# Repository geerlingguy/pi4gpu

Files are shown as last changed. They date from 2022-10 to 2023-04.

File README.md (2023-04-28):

# Pi4GPU - Raspberry Pi CM4 GPU Carrier Board

_a.k.a. 'PiG'_

This project contains the code and designs for a carrier board intended to unite a Raspberry Pi Compute Module 4 to any manufacturer's GPU.

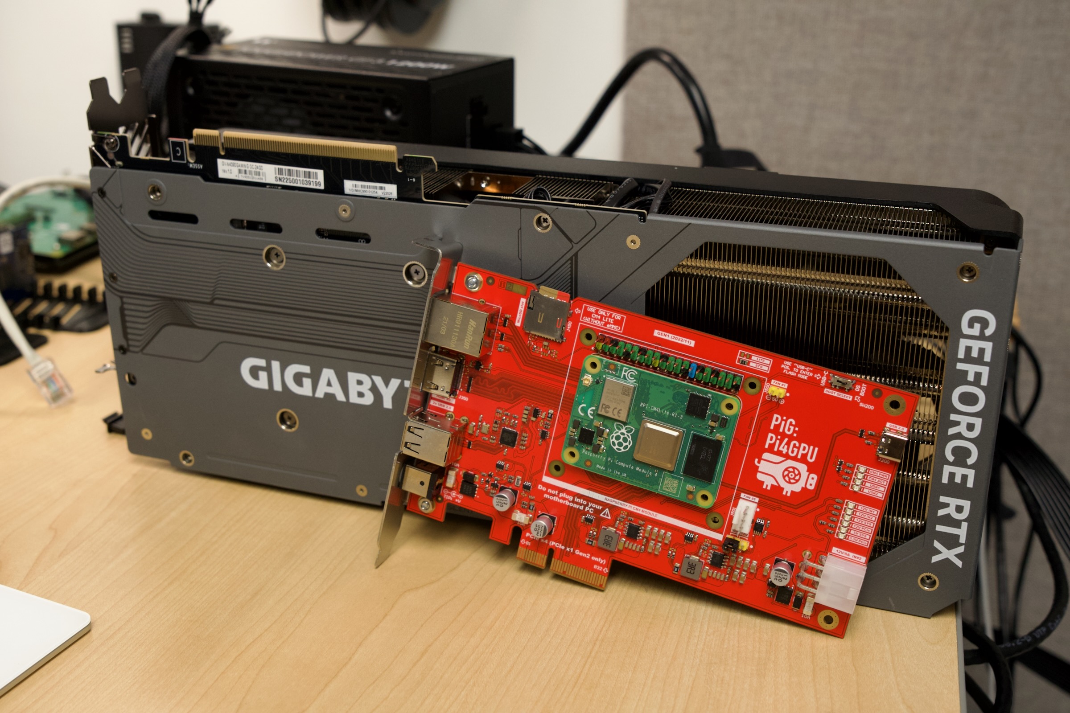
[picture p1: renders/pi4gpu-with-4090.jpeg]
Pi4GPU with Raspberry Pi Compute Module 4 in front of Nvidia GeForce RTX 4090


The board is not exclusively intended for GPU testing, though—this project is helpful for testing any kind of full-size PCI Express card with a Raspberry Pi Compute Module 4 or any CM4-compatible System on Modules (SoM).

## Goals

This project includes all the design files to build the Pi4GPU project:

  - **CM4 carrier board** (with PCIe x4 edge connection)
    - 1x full-size HDMI (rear)
    - 1x RJ45 Ethernet (rear)
    - 2x USB 2.0 (rear)
    - 1x 12v barrel power plug (rear)
    - 1x microSD card slot for Lite CM4 (top)
    - 4-pin PWM fan header with EMC2301 fan controller for optional fan (possibly)
  - **PCIe adapter board**
    - 1x x4 (x1 signaling) PCI Express slot for CM4 carrier board
    - 1x x16 (x1 signaling) PCI Express slot for GPU or other device
  - **3D printed stand**
    - Stable base for the Carrier board, extends to support 3+ slot GPUs
    - Mounting points for PCIe card brackets (in the future)

## Current Status

Early prototype. It works, but there are plenty of improvements to be made! Check out the issues for current work and future improvements.

## License

PCB project published as Open Source Hardware (OSHW) under CERN OHL v1.2 (Open Hardware License).

Pi4GPU has been certified as Open Source Hardware by the Open Source Hardware Association (OSHWA). 

UID is (for v1): PL000014

https://certification.oshwa.org/pl000014.html

UID is (for v2): PL000016

https://certification.oshwa.org/pl000016.html

## People

Pi4GPU was originally designed by:

  - [Jeff Geerling](https://www.jeffgeerling.com) (concept)
  - [@mfolejewski](https://github.com/mfolejewski) (PCB design)

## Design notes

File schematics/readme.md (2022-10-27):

# Description
Here you can find schematics files in PDF format

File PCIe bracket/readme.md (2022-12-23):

PCIe bracket ("Standard Add-in Card I/O Bracket") according to "PCI Express Card Electromechanical Specification Revision 3.0".

Designed by: Adam Nowak (with small modifications) based on the 3D model from GrabCAD: https://grabcad.com/library/pcie-brackets-1

Known issues:
- missing M3 threads (2 pcs) -> attached picture ("PCIe_bracket_M3_hole.png")
- missing bending -> attached picture ("PCIe_missing_bending.png")
- 3D model should be verified with the existing hardware

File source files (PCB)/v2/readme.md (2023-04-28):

## PCB project

Here the design files (schematic, PCB, BOM) can be viewed by using interactive service (Altium 365 platform):
https://365.altium.com/files/2EB381B2-202C-4C54-8FDE-9D991AE2ABAC

## License

Project published as Open Source Hardware (OSHW) under CERN OHL v1.2 (Open Hardware License).



Project (v2) has been certified as Open Source Hardware by the Open Source Hardware Association (OSHWA).

UID is (v2): PL000016

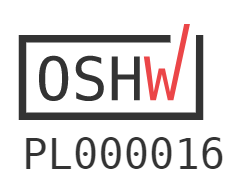
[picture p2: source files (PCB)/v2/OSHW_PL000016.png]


https://certification.oshwa.org/pl000016.html

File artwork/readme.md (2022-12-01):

PiG artwork has been designed by Senior Graphic Designer Krystyna Oniszczuk-Dylik:
https://www.linkedin.com/in/krystyna-oniszczuk-dylik-2559ab151/

Here you can download PNG and PDF file which contain this graphic design:
https://github.com/geerlingguy/pi4gpu/blob/master/artwork/PiG_2022-11-28.png
https://github.com/geerlingguy/pi4gpu/blob/master/artwork/PiG_2022-11-28.pdf

Here is preview of the artwork placed on the PCB:
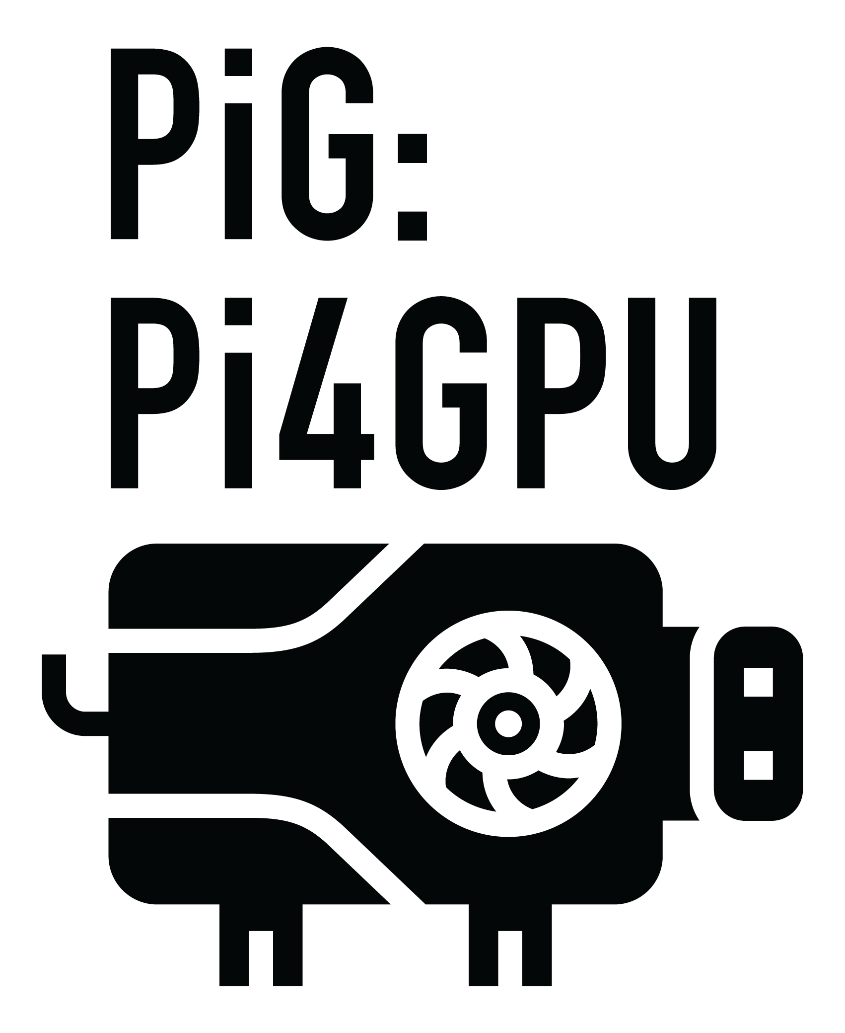
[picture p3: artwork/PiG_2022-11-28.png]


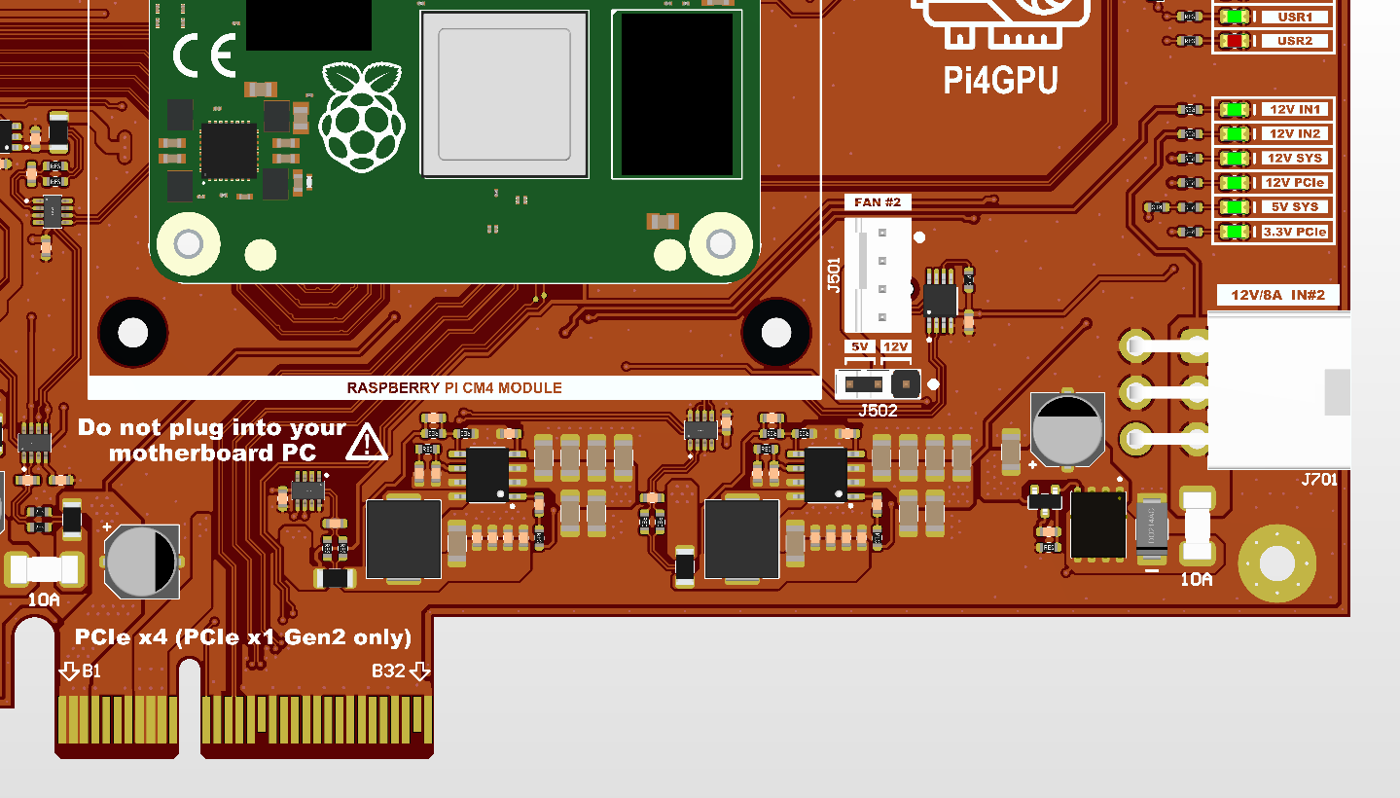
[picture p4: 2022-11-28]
renders/Pi4GPU_2022-11-29_4.png

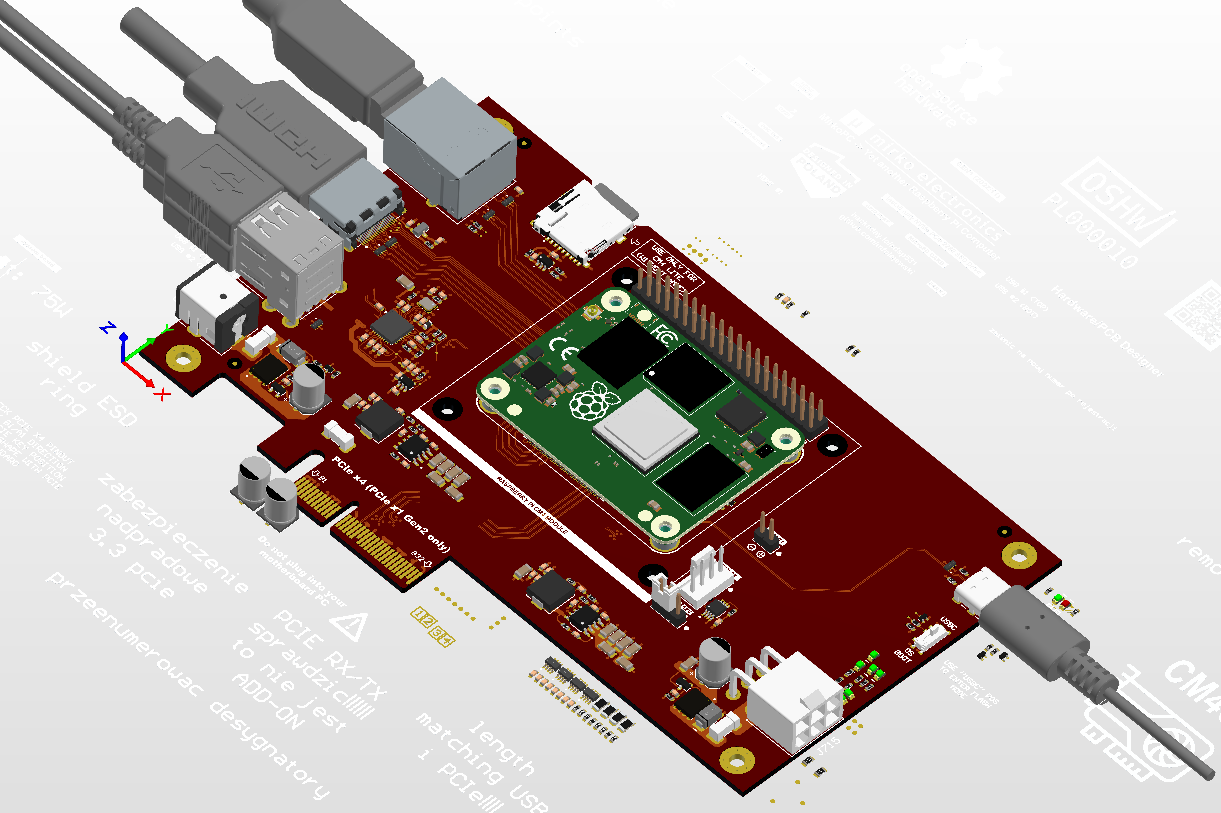
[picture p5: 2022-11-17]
renders/CM4GPU_PCB_20221117_04.png

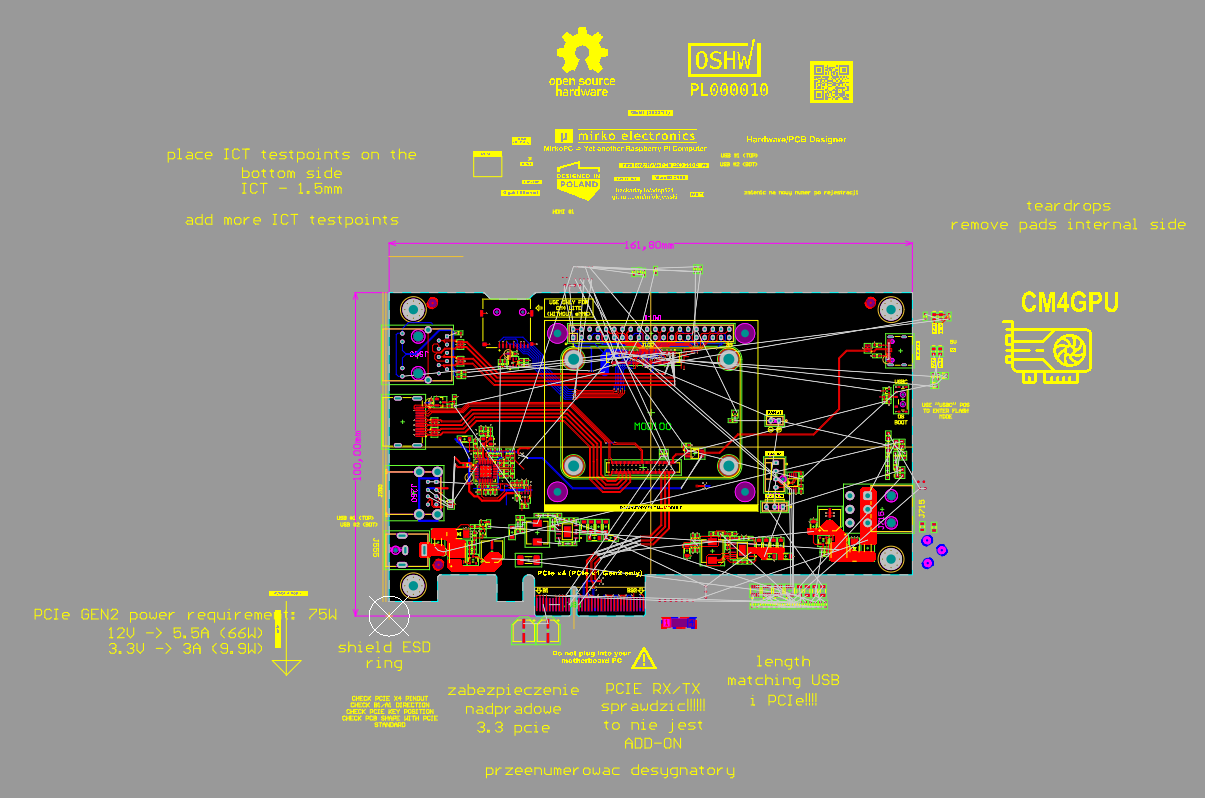
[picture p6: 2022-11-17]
renders/CM4GPU_PCB_20221117_01.png

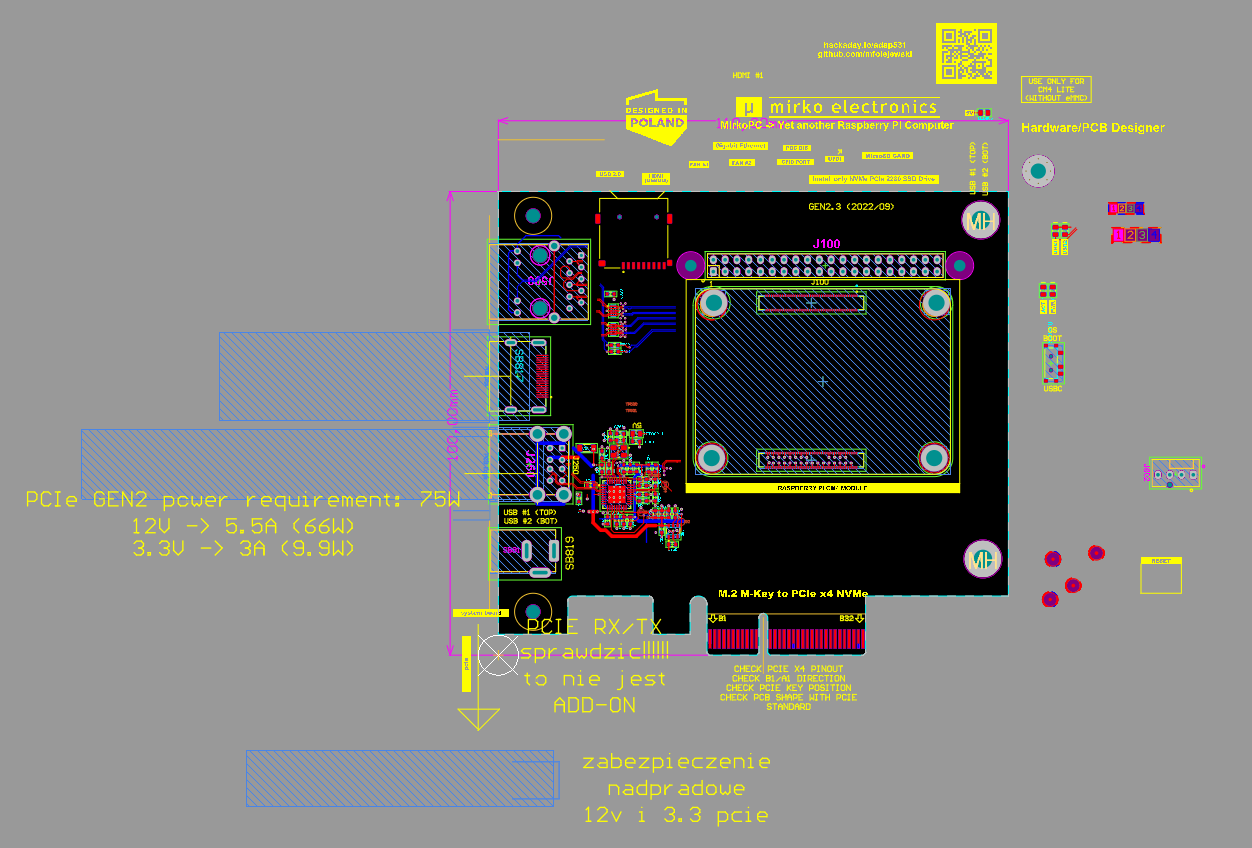
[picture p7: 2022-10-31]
renders/CM4GPU_PCB_20221031_04.png

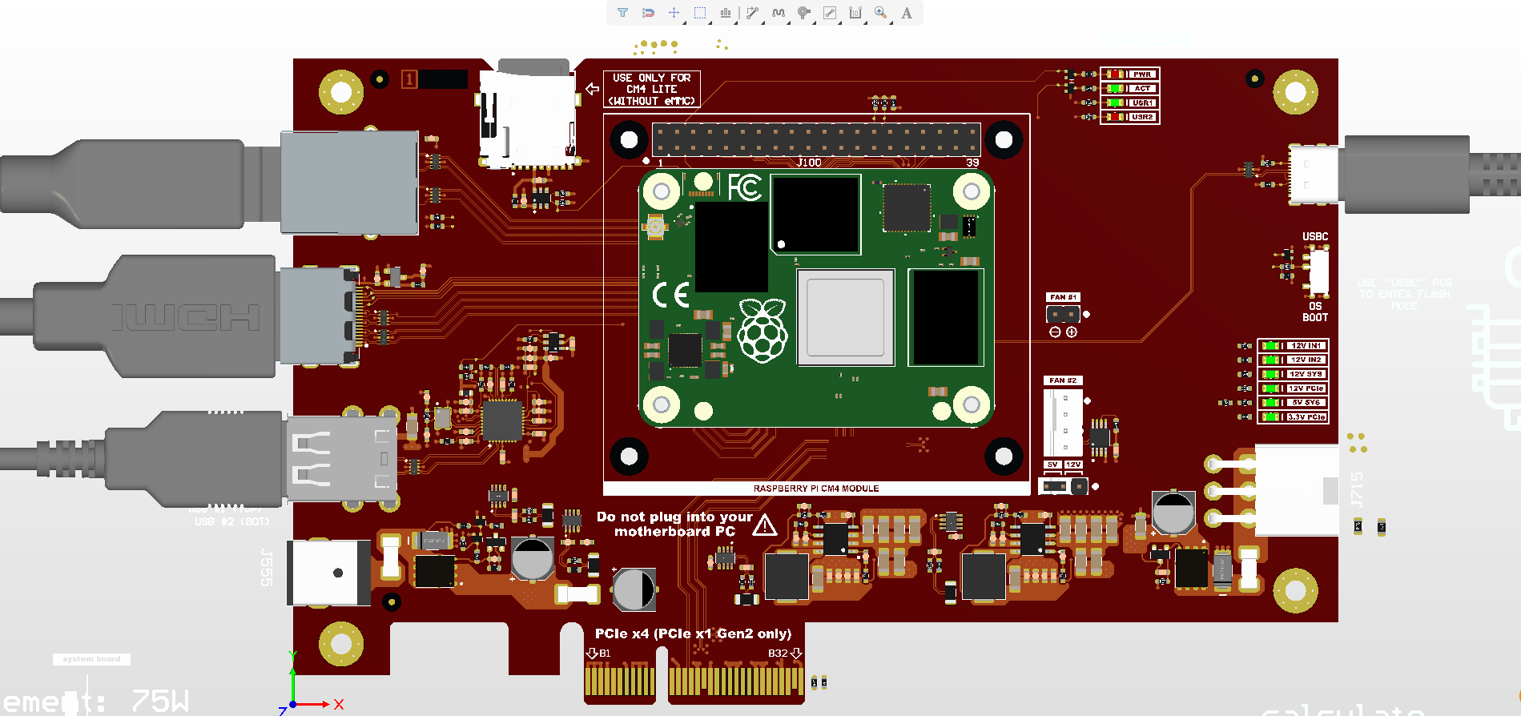
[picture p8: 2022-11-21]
renders/Pi4GPU_2022-11-21_1.png

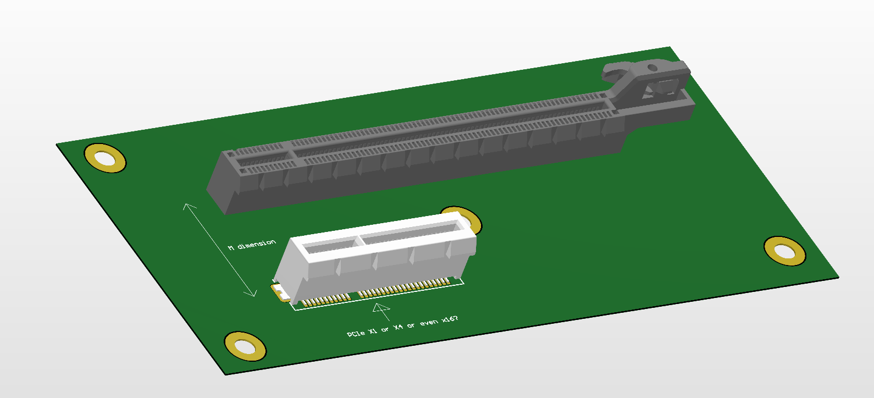
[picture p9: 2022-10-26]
renders/PCIE_adapter1.png

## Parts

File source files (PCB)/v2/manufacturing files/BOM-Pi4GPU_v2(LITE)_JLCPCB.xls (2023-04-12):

Comment | Designator | Footprint | LCSC PN
0R | R450 | 0603 (1608) | C21189
0R | R900 | 0805 (2012) | C17477
0.004R | R807 | 1206 (3216) | C5120913
0.012R | R800, R806, R812 | 1206 (3216) | C723448
0.016R | R801 | 1206 (3216) | C2904218
1k | R200, R203 | 0603 (1608) | C21190
1M | R256 | 0603 (1608) | C22935
1.2nF | C765, C781 | 0603 (1608) | C1853470
2k | R101, R102, R104, R106, R502 | 0603 (1608) | C22975
2k26 | R760 | 0603 (1608) | C22904
3.3uH | L750, L751 | SMD | C524605
4u7 | C256, C261 | 0603 (1608) | C19666
5k1 | R201, R202 | 0603 (1608) | C23186
8A, 2.0mm | J700 | THT | 490-PJ-063AH
10A/125VDC | FUS700, FUS701, FUS702 |  | C2838934
10k | R103, R252, R253, R254, R255 | 0603 (1608) | C98220
10R | R750, R755 | 0603 (1608) | C22859
10uF | C250, C252, C253, C254, C255, C451 | 0603 (1608) | C19702
10uF/10V | C755, C756, C757, C758, C771, C772, C773, C774 | 0603 (1608) | C19702
10uF/35V | C703, C751, C752, C753, C761, C762, C763, C767, C768, C769, C777, C778, C779 | 1206 (3216) | C92797
12k | R250 | 0603 (1608) | C22790
12k | R251, R753, R757 | 0603 (1608) | C22790
12V | D700, D702 |  | C896784
15k | R105, R501, R703, R709, R751, R756, R758 | 0603 (1608) | C22809
15k | R754 | 0603 (1608) | C22809
18pF | C266, C267 | 0603 (1608) | C1647
20k | R759 | 0603 (1608) | C4184
24.000MHz | X250 |  | C5261153
40pin (2x20pin) | J100 |  | C124383
47k | R752 | 0603 (1608) | C25819
100k | R700, R701 | 0603 (1608) | C25803
100nF | C200, C257, C258, C259, C260, C262, C263, C350, C351, C400, C750, C760, C766, C776, C803 | 0603 (1608) | C14663
100nF/50V | C700, C702 | 0603 (1608) | C14663
100R | R100, R107, R108, R109, R258 | 0603 (1608) | C22775
100uF/6V3 | C251 | 1206 (3216) | C15008
100uF/10V | C759, C775 | 1206 (3216) | C15008
120 Ohm | F250 | 0603 (1608) | C62708
220uF/25V | C701, C704, C705 | SMD SIZE D8 | C2918361
470R | R400, R401 | 0603 (1608) | C23179
AP2331 | U352 | SC59 | C460346
AP2553W6-7 | U250 | SOT26 | C212302
AP64501SP-13 | U750, U751 |  | C2071517
CON HDR 1x2 | J500 | THT | C492401
DTA143ZE | Q100, Q101 |  | C600679
DTC143ZE | Q200, Q500 |  | C248787
FSUSB42 | U200 | MSOP-10 | C255478
Green | LED100, LED500, LED700, LED701, LED750, LED751 | 0805 (2012) | C84260
HY911130A | J400 |  | C55679
Mezzanine, 100pin, 3.0mm | J101, J102 | SMD | C424649
MicroSD Card (Slot) | J450 | SMD | C113206
Molex 2x3P 4.2mm | J701 | THT | C54904
PCB BARE BOARD | PCB1
PMOS | Q700, Q703 | PowerPAK-SO-8 | C554002
RCLAMP0524PA | U201, U252, U350, U351, U400, U401 | TBD | C40960
Red | LED101, LED501 | 0805 (2012) | C84256
RPi CM4 Module | MOD100
Slide switch | SW200 | SMD | C397350
SMAJ12A | D701, D703 |  | C713694
SPST | SW100, SW101 | SMD | C110293
Standdard HDMI (Type A) | J350 | SMD | C138388
U262-161N-4BVC11 | J200 | SMD | C319148
USB2512B | U251 |  | C626658
USB Type A (Dual) | J250 | THT | C456021

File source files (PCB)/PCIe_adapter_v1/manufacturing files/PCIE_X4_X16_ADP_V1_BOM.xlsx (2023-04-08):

Designator | Quantity | Component Type | Value | Package (Case) | Manufacturer | MPN | Description
J1 | 1 |  | PCIE x16, 164P, SMD |  | UMAX | 91621-120113N | Connector; PCIE x16 (164 pin)
J2 | 1 |  | PCIE x4, 64P, SMD |  | UMAX | UMAX 3113-111T | Connector; PCIE x4 (64 pin)
R1, R2, R3, R4, R5, R6, R7, R8, R9, R10 | 10 | Resistor | DNP | 0603 (1608) | TBD | TBD | Resistor; Thick Film; DNP; TBD; TBD; TBD; TBD; DO NOT PLACE; SMD; 0603 (1608);

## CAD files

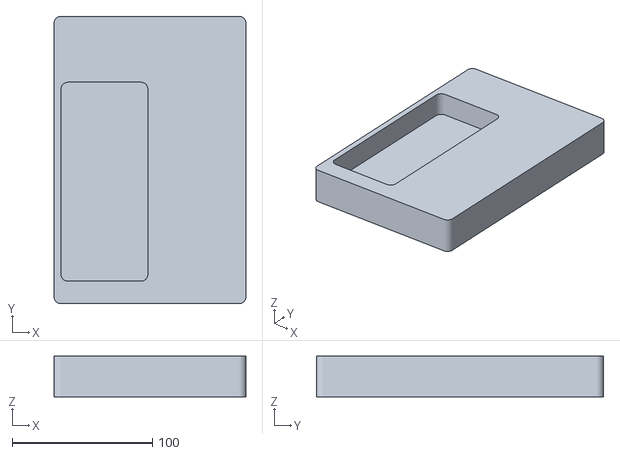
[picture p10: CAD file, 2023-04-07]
3d-models/gpu-stand.stl
137.0 x 205.0 x 29.0

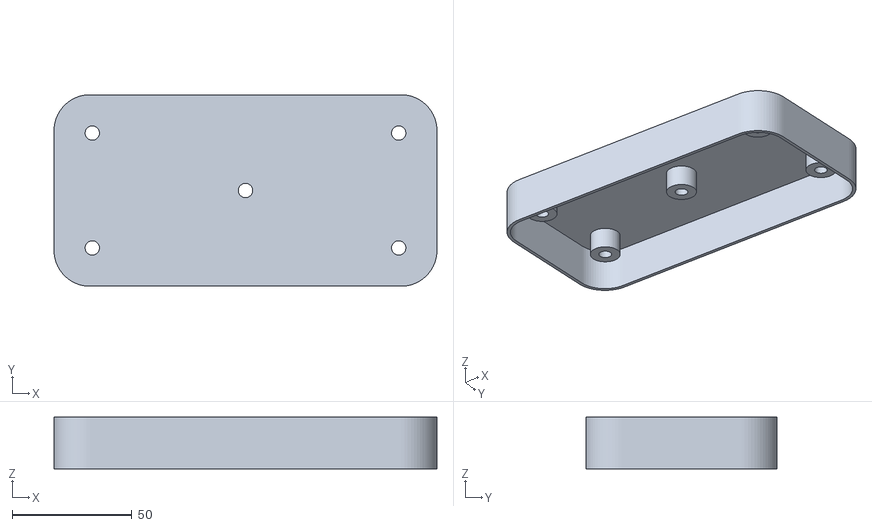
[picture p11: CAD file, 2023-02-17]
STEP models/PCIE_X4_X16_ADP_stand_v1.stl
160.0 x 80.0 x 21.6

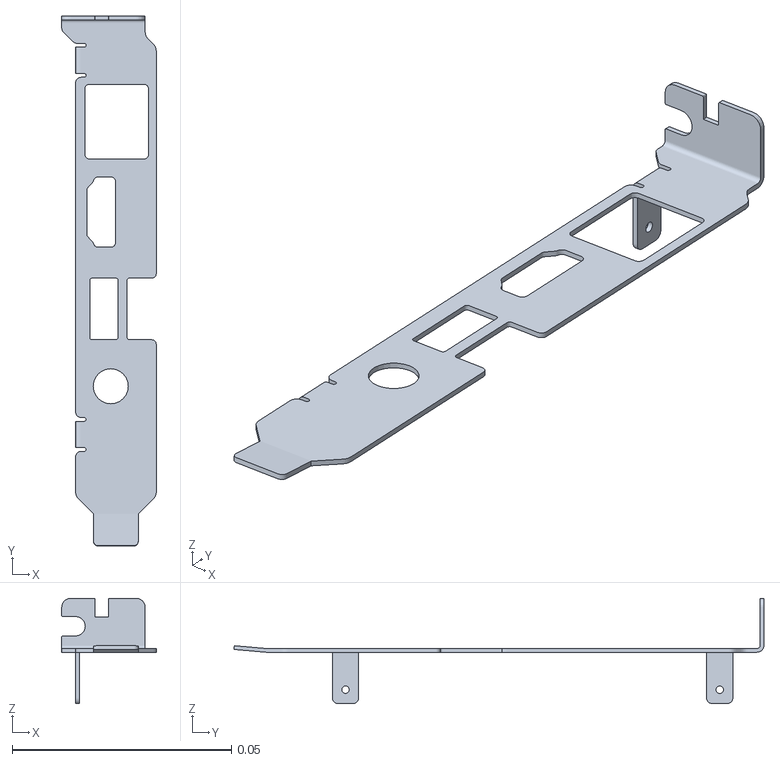
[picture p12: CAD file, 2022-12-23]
PCIe bracket/PCIE card IO panel.stl
0.0216 x 0.121 x 0.024

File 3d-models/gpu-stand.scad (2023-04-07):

$fn = $preview ? 32 : 64;

// Main body.
translate([5, 5, 0])
    difference() {
        minkowski() {
            cube(size = [127,195,28], center = false);
            cylinder(r=5, h=1, center = false);
        }
        translate([5, 16, 10]) {
            minkowski() {
                cube(size = [52,132,20], center = false);
                cylinder(r=5, h=28, center = false);
            }
        }
    }

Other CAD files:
PCIe bracket/PCIE card IO panel 4 mif.DWG

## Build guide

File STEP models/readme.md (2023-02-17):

Here you can download 3D STEP models of PCB boards and other parts:

PCIE_X4_X16_ADP_stand_v1.stl -> simple stand for test setup (v1)
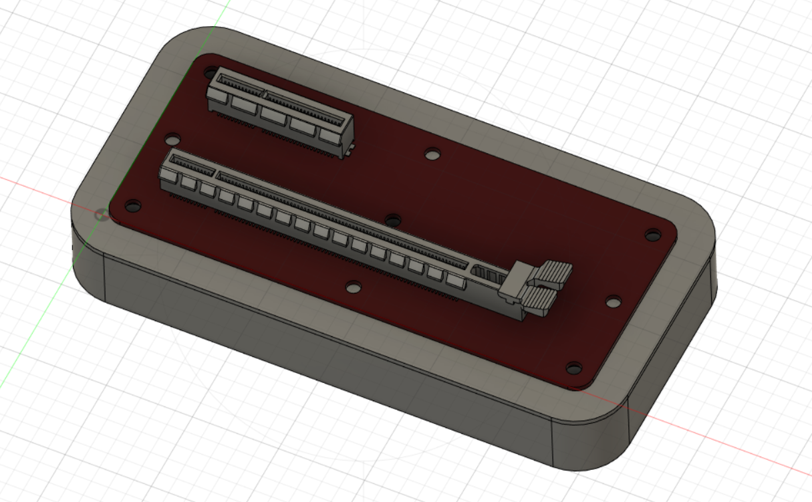
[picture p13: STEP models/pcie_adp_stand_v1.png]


PCIE_X4_X16_ADP_V1_STEP_3D_2022-12-20.7z -> PCIe X4-X16 adapter (PCB + all the components)
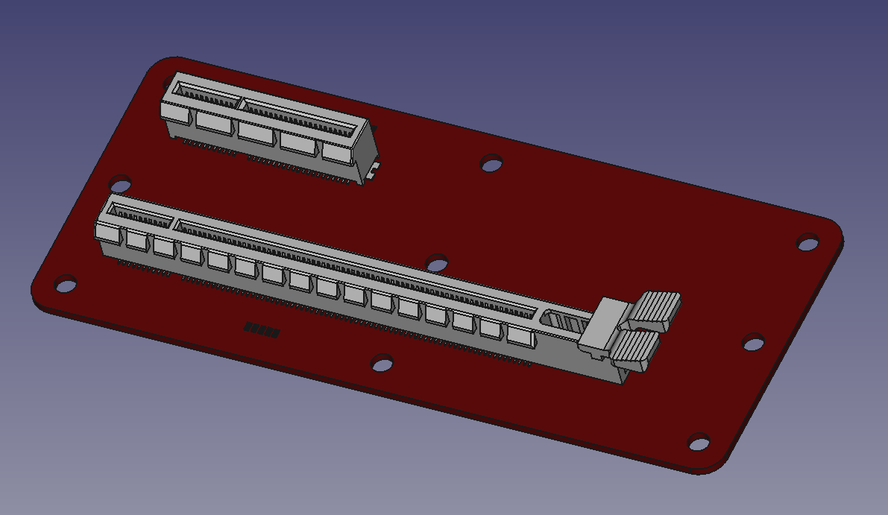
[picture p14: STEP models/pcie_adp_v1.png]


Pi4GPU_v1_3D_model_20221129_full.7z -> (PCB + all the components)
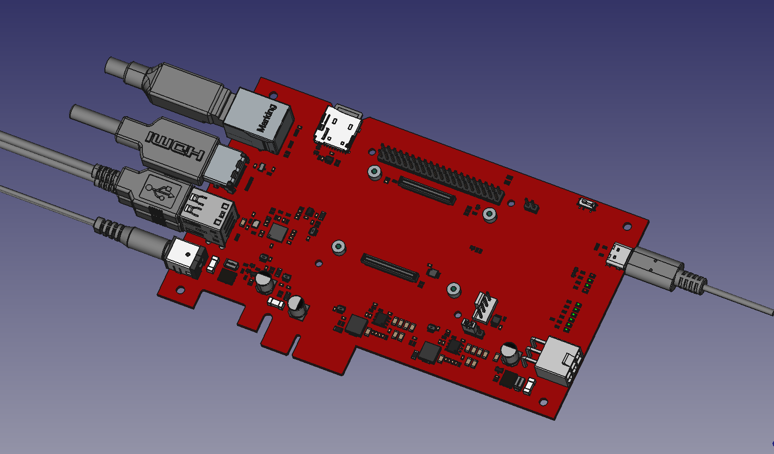
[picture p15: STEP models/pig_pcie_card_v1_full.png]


Pi4GPU_v1_3D_model_20221129_conn_only.7z -> (PCB + front connectors only)
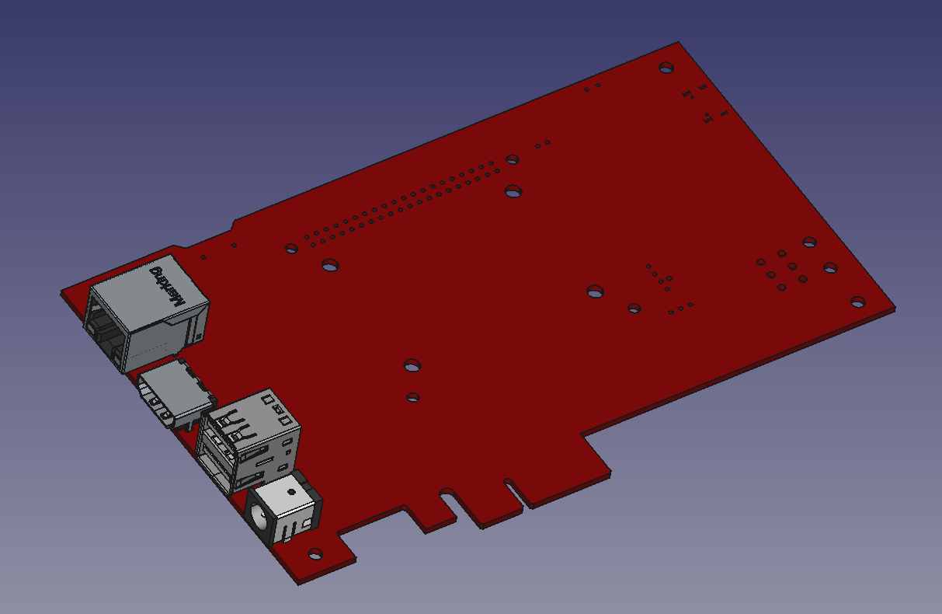
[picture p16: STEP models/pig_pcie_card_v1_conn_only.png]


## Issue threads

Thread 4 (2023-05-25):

[feature idea] power options

8bitbunny, 2023-05-25:
i there are multiple options for powering this unit (pcie 6pin, dc barrel), which is nice

one feature i do suggest for a faster and more convenient install: putting the pcie 6 pin connector on the pcie bridge to both gpu and pi4gpu card using different connectors, like 8 pin pcie, or eps12v, or atx12vo?
just so theres cables to deal with when swapping pi4gpu card and you have more modularity power wise.

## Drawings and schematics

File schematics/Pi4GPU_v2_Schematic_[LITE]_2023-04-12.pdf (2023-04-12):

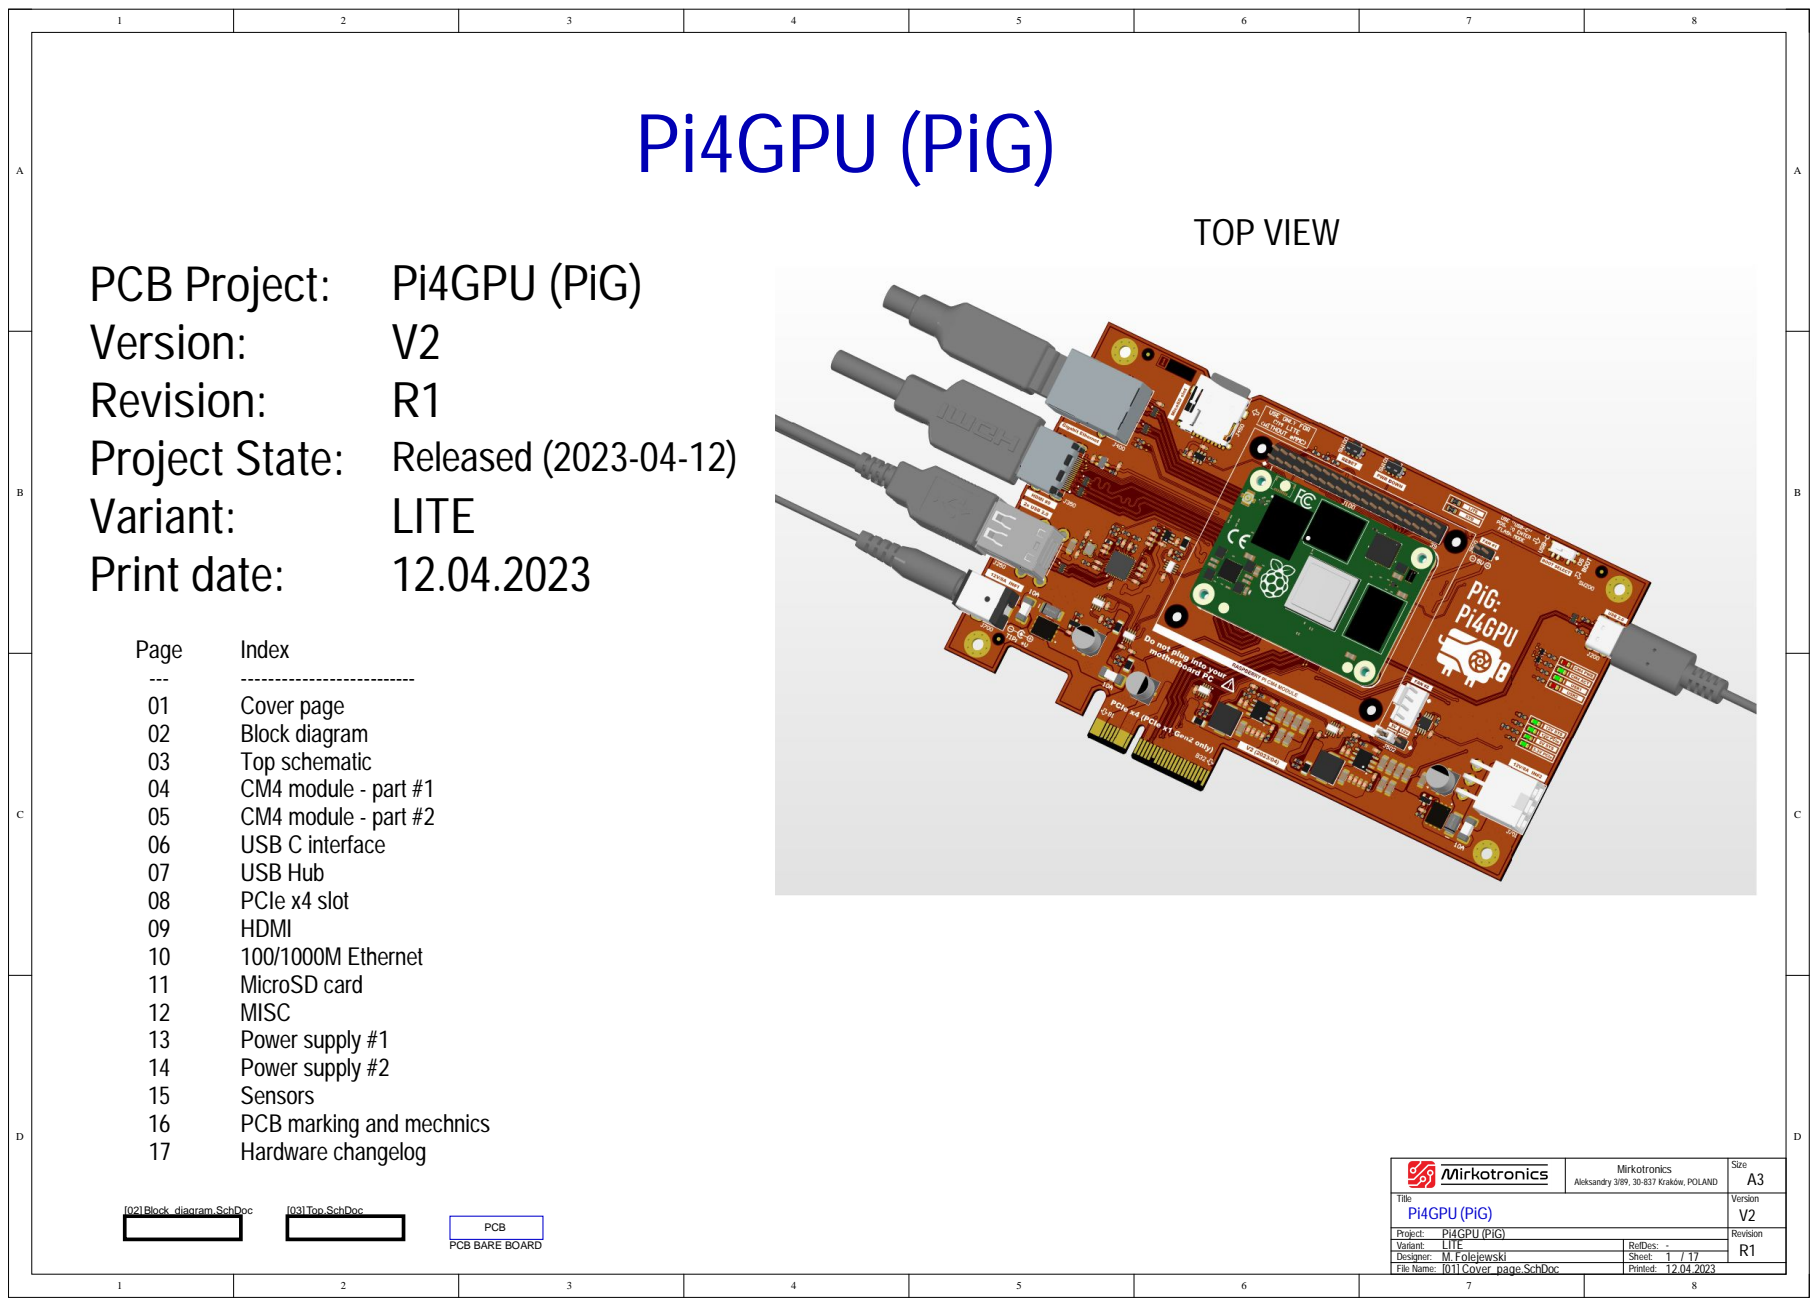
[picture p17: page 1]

Mirkotronics Aleksandry 3/89, 30-837 Kraków, POLAND | Size A3

Title Pi4GPU (PiG) | | Version V2

Revision R1
Variant: LITE
Designer: M. Folejewski
File Name: [01] Cover_page.SchDoc | Printed:

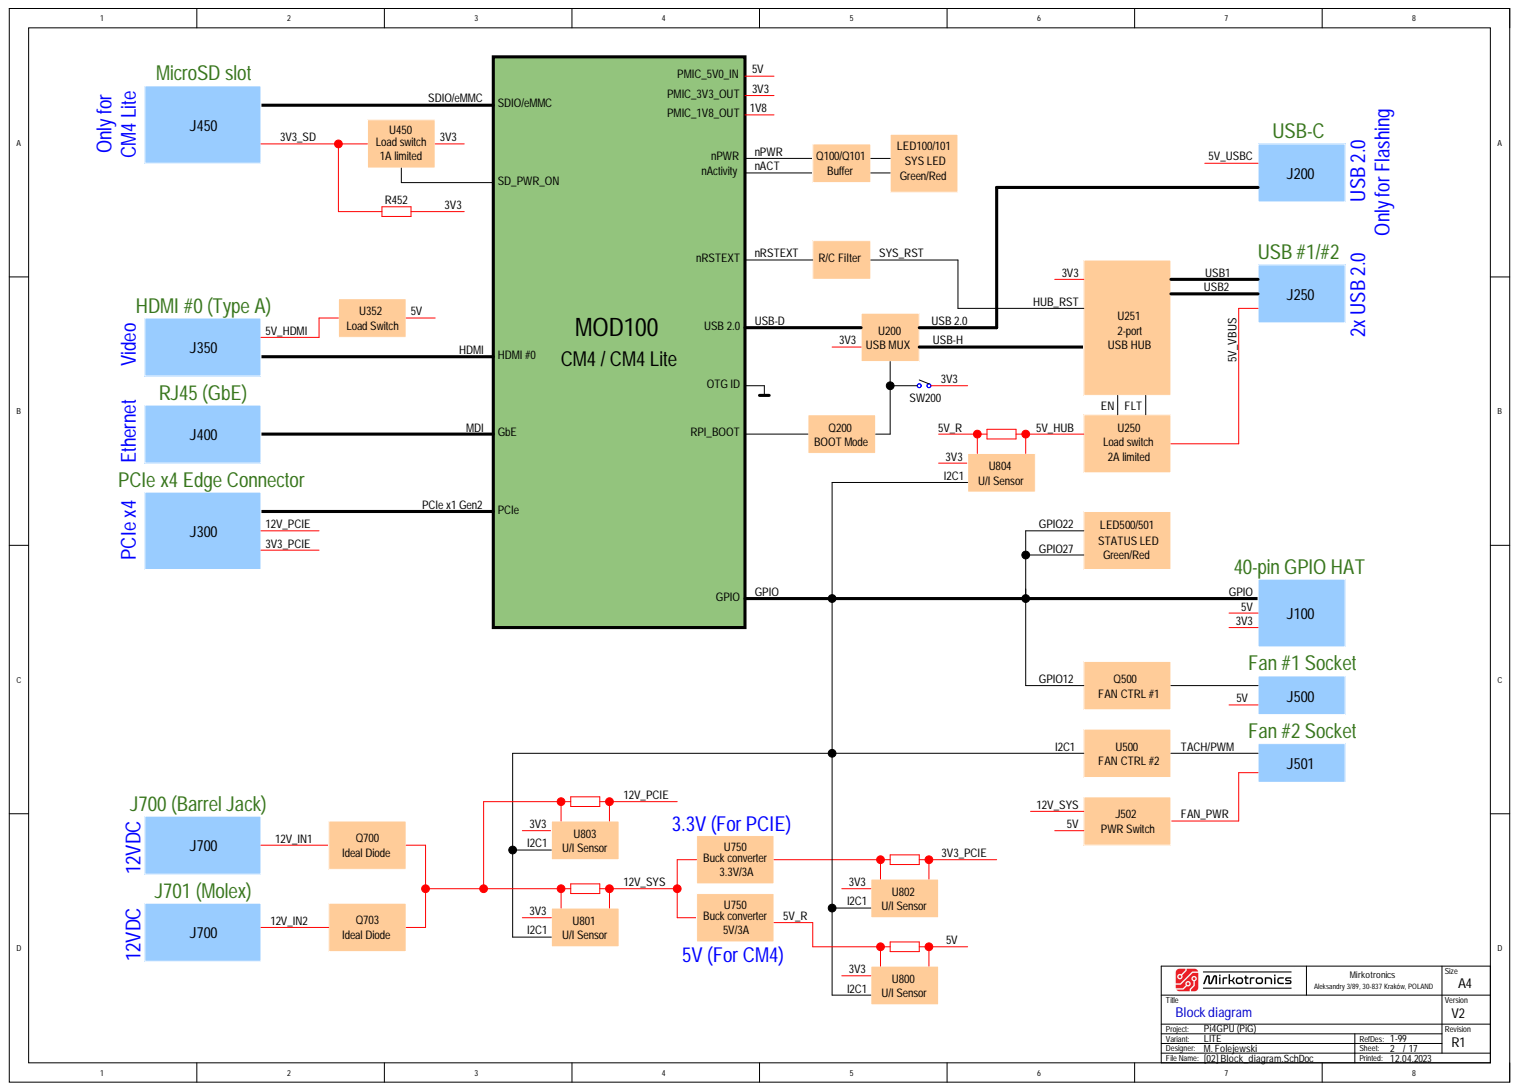
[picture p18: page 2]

SDIO/eMMC

Title Block diagram | Version V2

Revision R1
Variant: LITE

File Name: [02] Block_diagram.SchDoc | Printed:

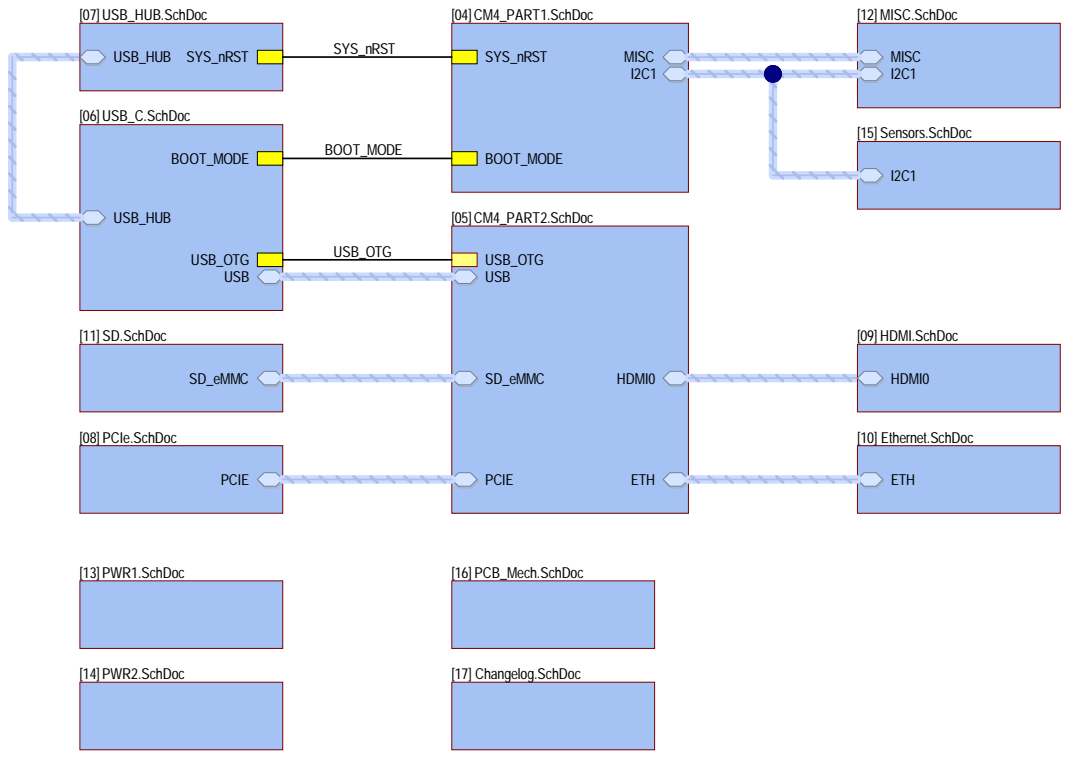
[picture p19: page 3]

Mirkotronics Aleksandry 3/89, 30-837 Kraków, POLAND | Size A4

Title Top schematic | | Version V2

Project: Pi4GPU (PiG) | | Revision R1
Variant: LITE | RefDes: 1-99

Sheet: 3 17 /

File Name: [03] TOP.SchDoc | Printed: 12.04.2023

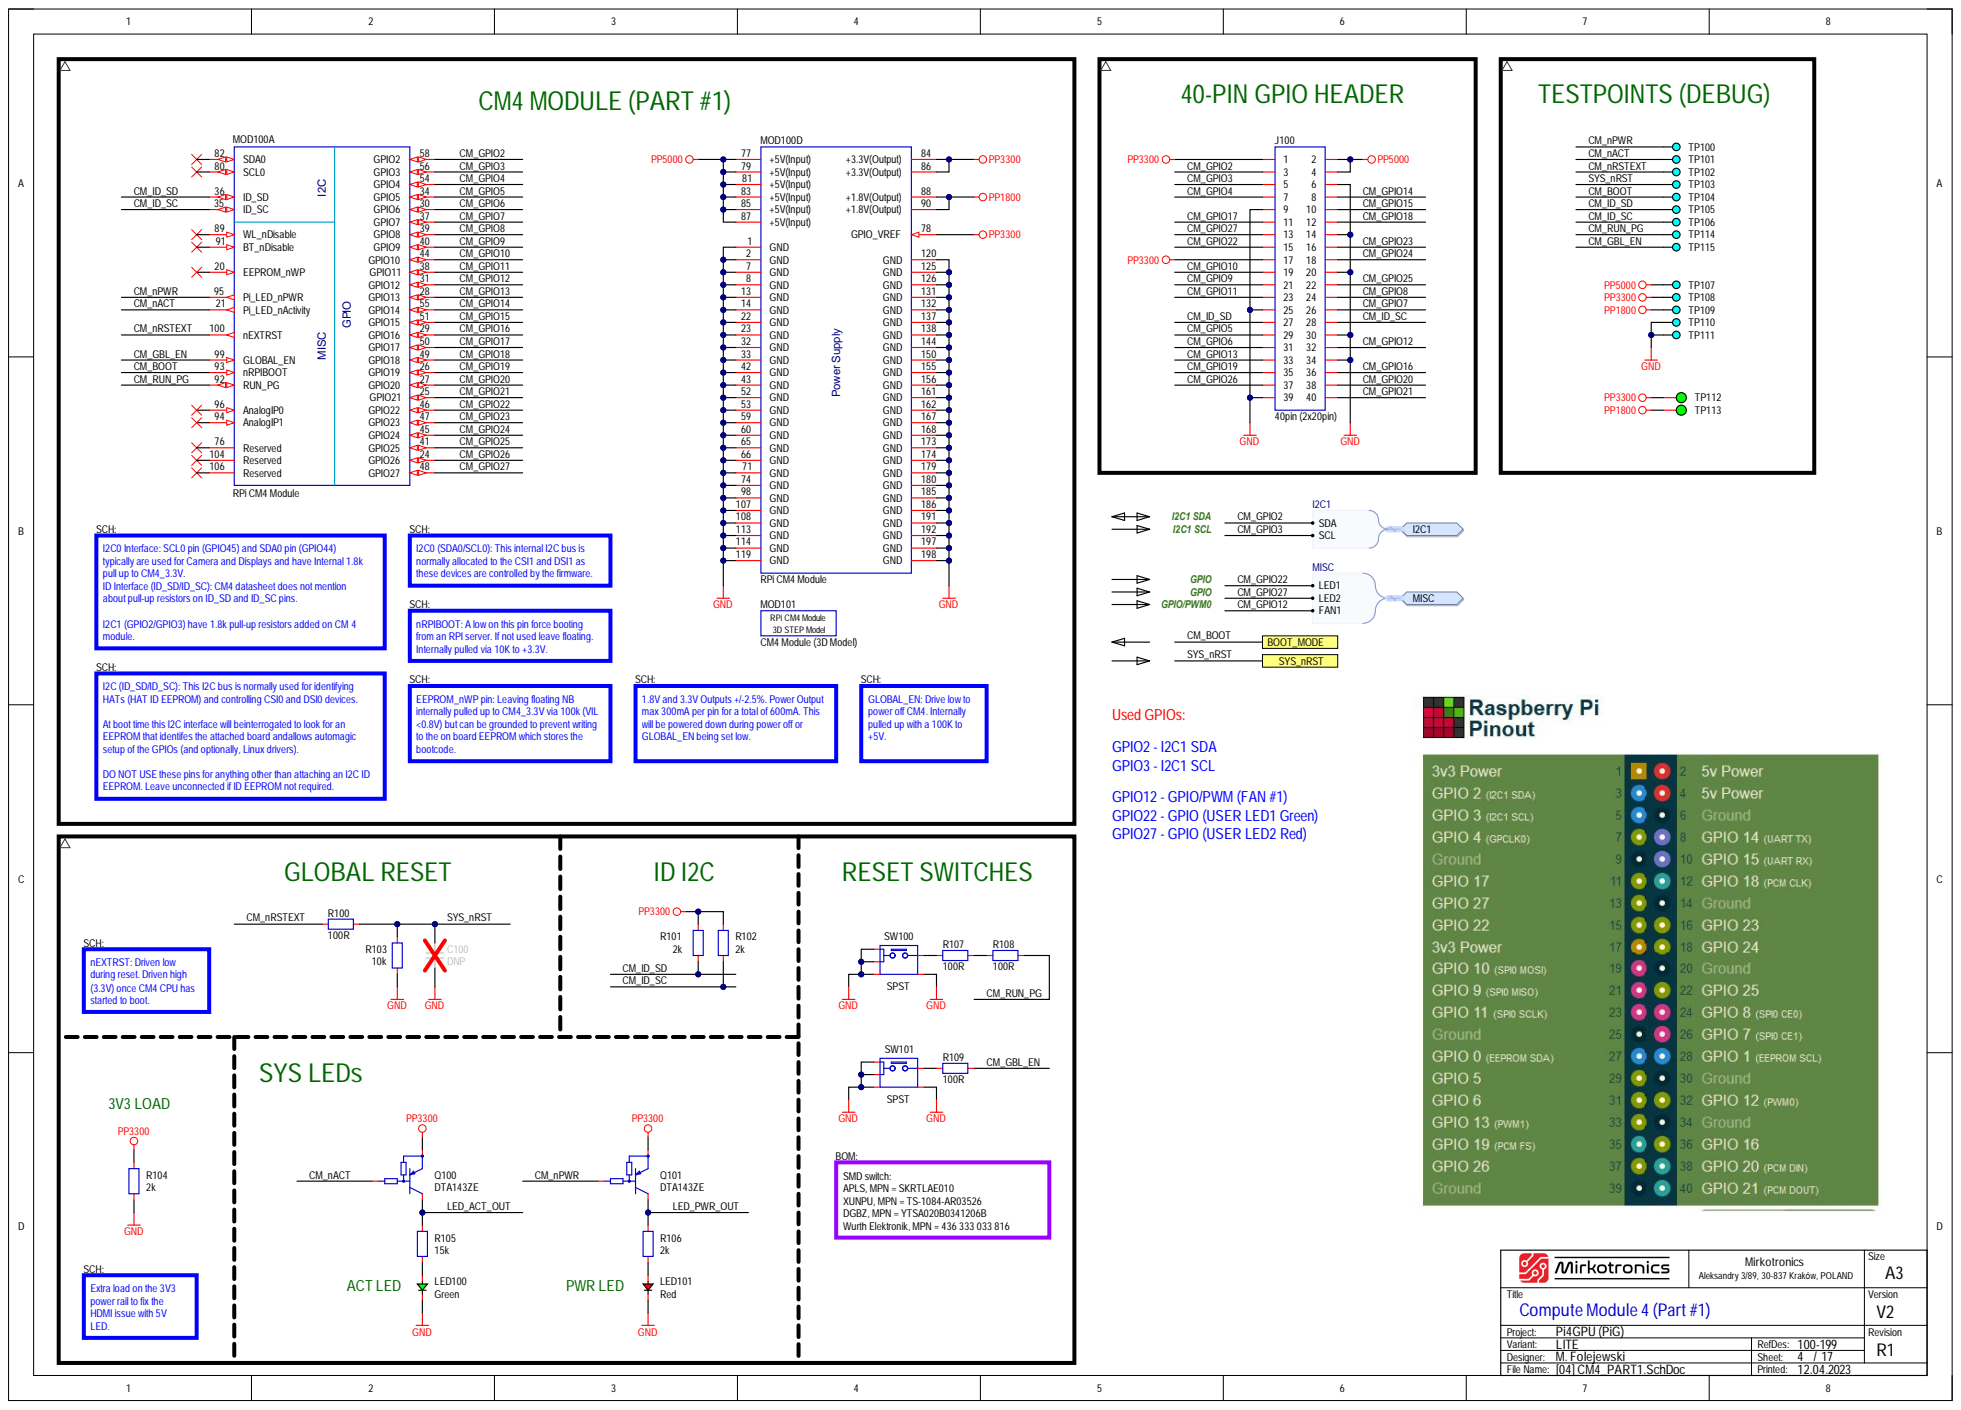
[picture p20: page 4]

SCH:
I2C0 Interface: SCL0 pin (GPIO45) and SDA0 pin (GPIO44)
typically are used for Camera and Displays and have Internal 1.8k
pull up to CM4_3.3V.
ID Interface (ID_SD/ID_SC): CM4 datasheet does not mention
about pull-up resistors on ID_SD and ID_SC pins.

I2C0 (SDA0/SCL0): This internal I2C bus is
normally allocated to the CSI1 and DSI1 as
these devices are controlled by the firmware.

nRPIBOOT: A low on this pin force booting
from an RPI server. If not used leave floating.
Internally pulled via 10K to +3.3V.

I2C1 (GPIO2/GPIO3) have 1.8k pull-up resistors added on CM4
module.

I2C (ID_SD/ID_SC): This I2C bus is normally used for identifying
HATs (HAT ID EEPROM) and controlling CSI0 and DSI0 devices.

EEPROM_nWP pin: Leaving floating NB
internally pulled up to CM4_3.3V via 100k (VIL
<0.8V) but can be grounded to prevent writing
to the on board EEPROM which stores the
bootcode.

1.8V and 3.3V Outputs +/-2.5%. Power Output
max 300mA per pin for a total of 600mA. This
will be powered down during power off or
GLOBAL_EN being set low.

GLOBAL_EN: Drive low to
power off CM4. Internally
pulled up with a 100K to

At boot time this I2C interface will beinterrogated to look for an
EEPROM that identifes the attached board andallows automagic
setup of the GPIOs (and optionally, Linux drivers).

DO NOT USE these pins for anything other than attaching an I2C ID
EEPROM. Leave unconnected if ID EEPROM not required.

nEXTRST: Driven low
during reset. Driven high
(3.3V) once CM4 CPU has
started to boot.

Mirkotronics Aleksandry 3/89, 30-837 Kraków, POLAND | Size A3

Extra load on the 3V3
power rail to fix the
HDMI issue with 5V
LED.

Title Compute Module 4 (Part #1) | | Version V2

Revision R1
Variant: LITE

File Name: [04] CM4_PART1.SchDoc | Printed:

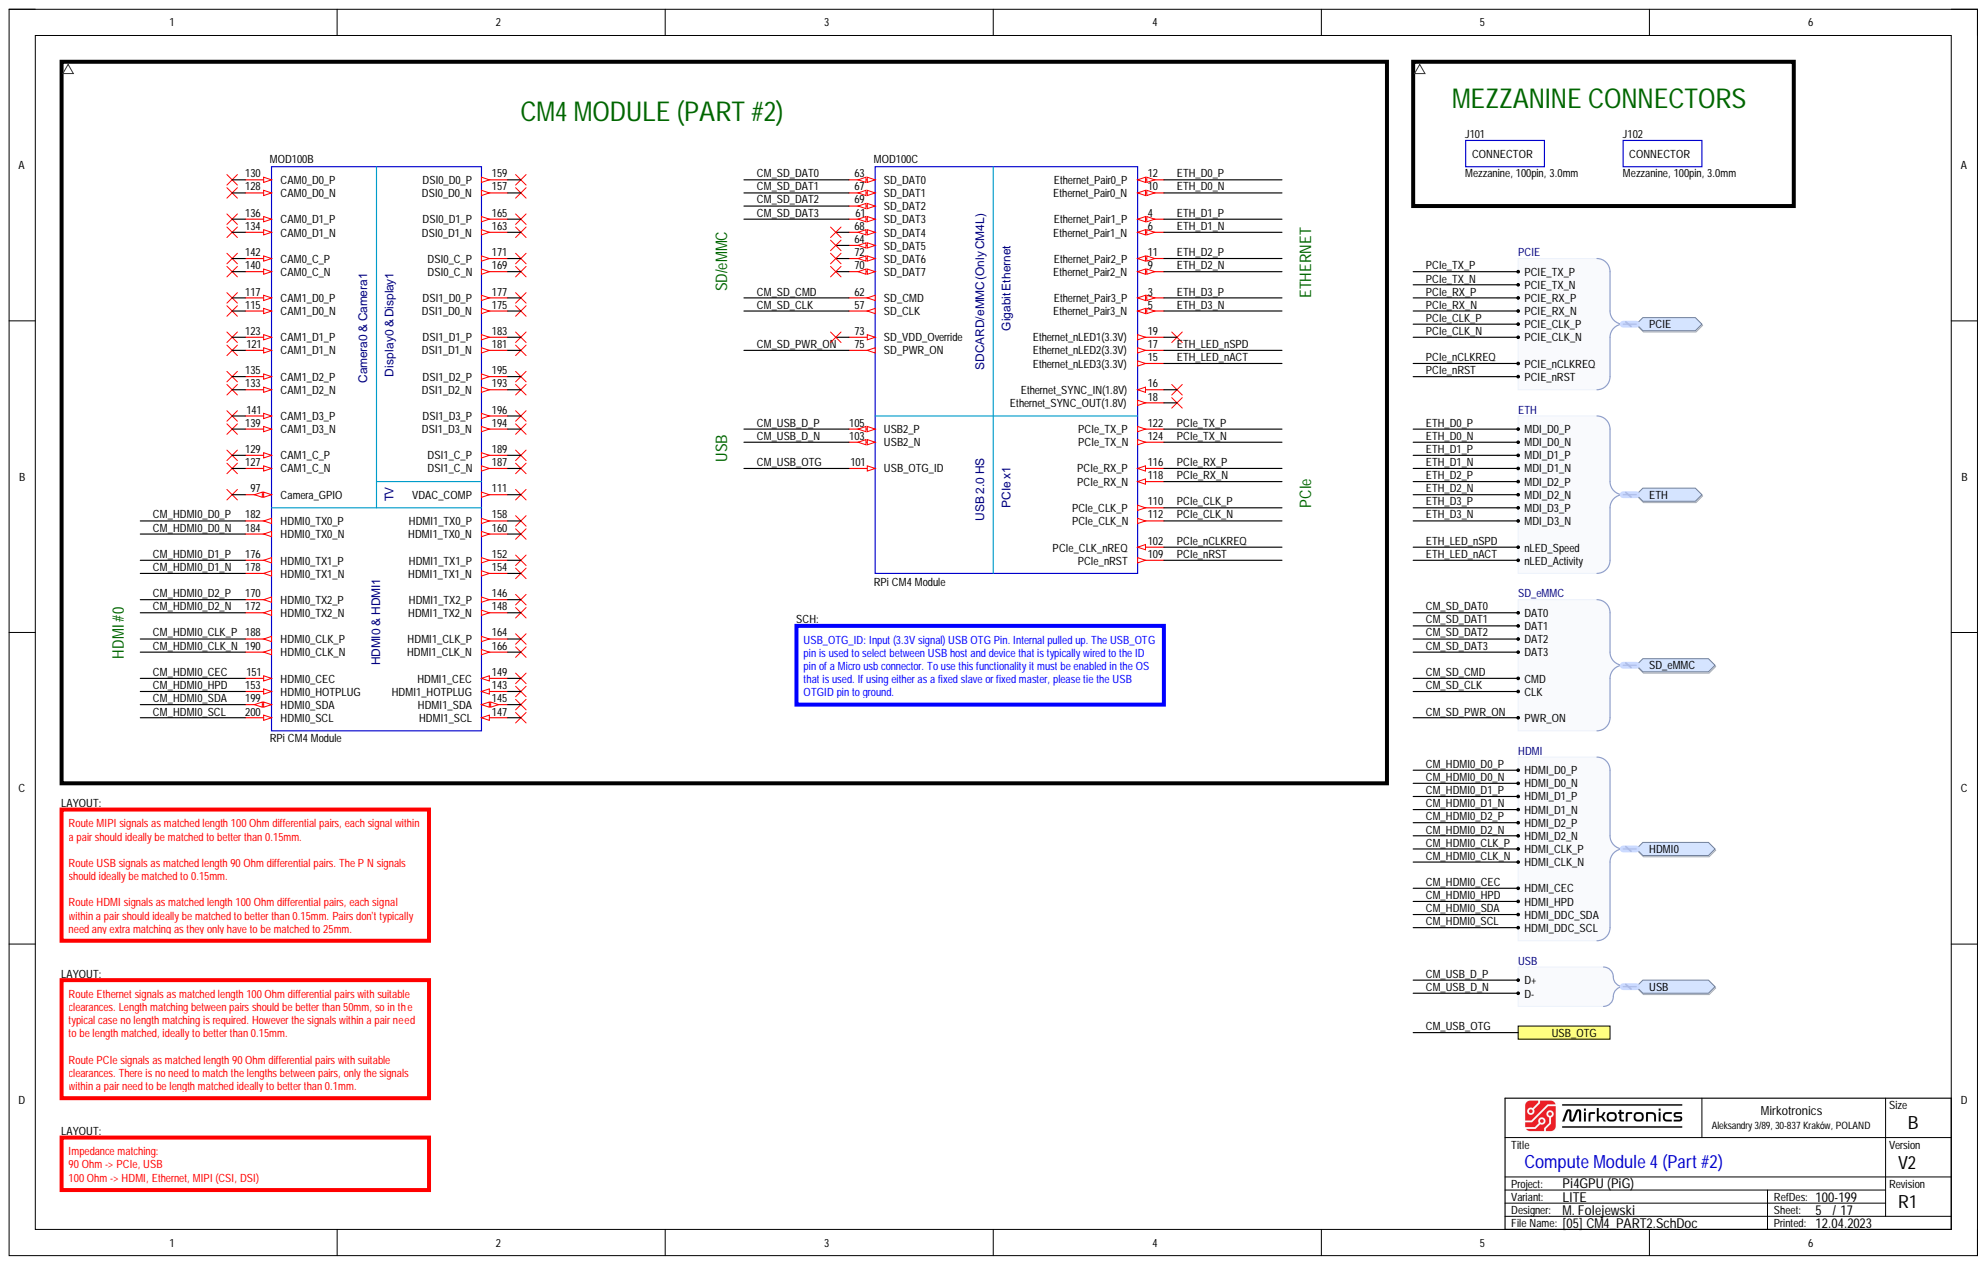
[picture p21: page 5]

SDCARD/eMMC(Only CM4L) USB 2.0 HS

select between USB host and devi
connector. To use

Revi sion R1
Variant: LITE
M. Folejewski Designer: | Sheet:
Fi le Name: [05] CM4_PART2.SchDoc | Printed:

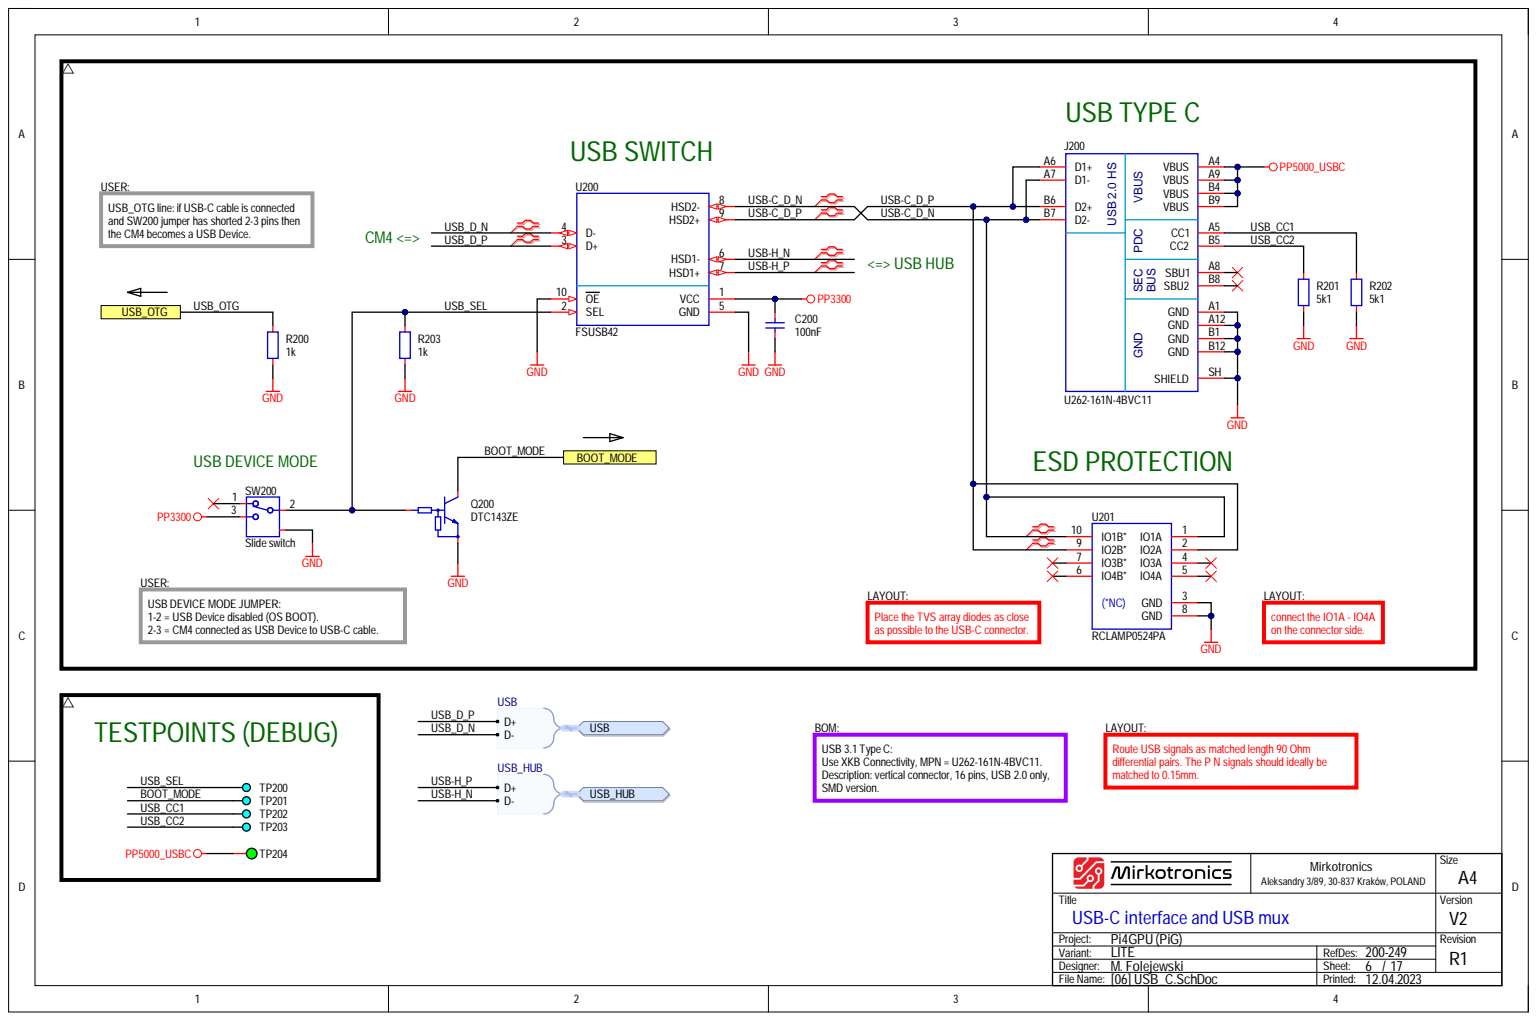
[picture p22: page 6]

D1+ A6 | VBUS
D1- A7 | A9
D2+ B6 | B4

GND VBUS PDC SEC

USER:
USB_OTG line: if USB-C cable is connected
and SW200 jumper has shorted 2-3 pins then
the CM4 becomes a USB Device.

USB DEVICE MODE JUMPER:
1-2 = USB Device disabled (OS BOOT).
2-3 = CM4 connected as USB Device to USB-C cable.

Place the TVS array diodes as close
as possible to the USB-C connector.

connect the IO1A - IO4A
on the connector side.

BOM:
USB 3.1 Type C:
Use XKB Connectivity, MPN = U262-161N-4BVC11.
Description: vertical connector, 16 pins, USB 2.0 only,
SMD version.

LAYOUT:
Route USB signals as matched length 90 Ohm
differential pairs. The P N signals should ideally be
matched to 0.15mm.

Mirkotronics Aleksandry 3/89, 30-837 Kraków, POLAND | Size A4

Title USB-C interface and USB mux | | Version V2

Project: Pi4GPU (PiG) | | Revision R1
Variant: LITE | RefDes: 200-249

File Name: [06] USB_C.SchDoc | Printed:

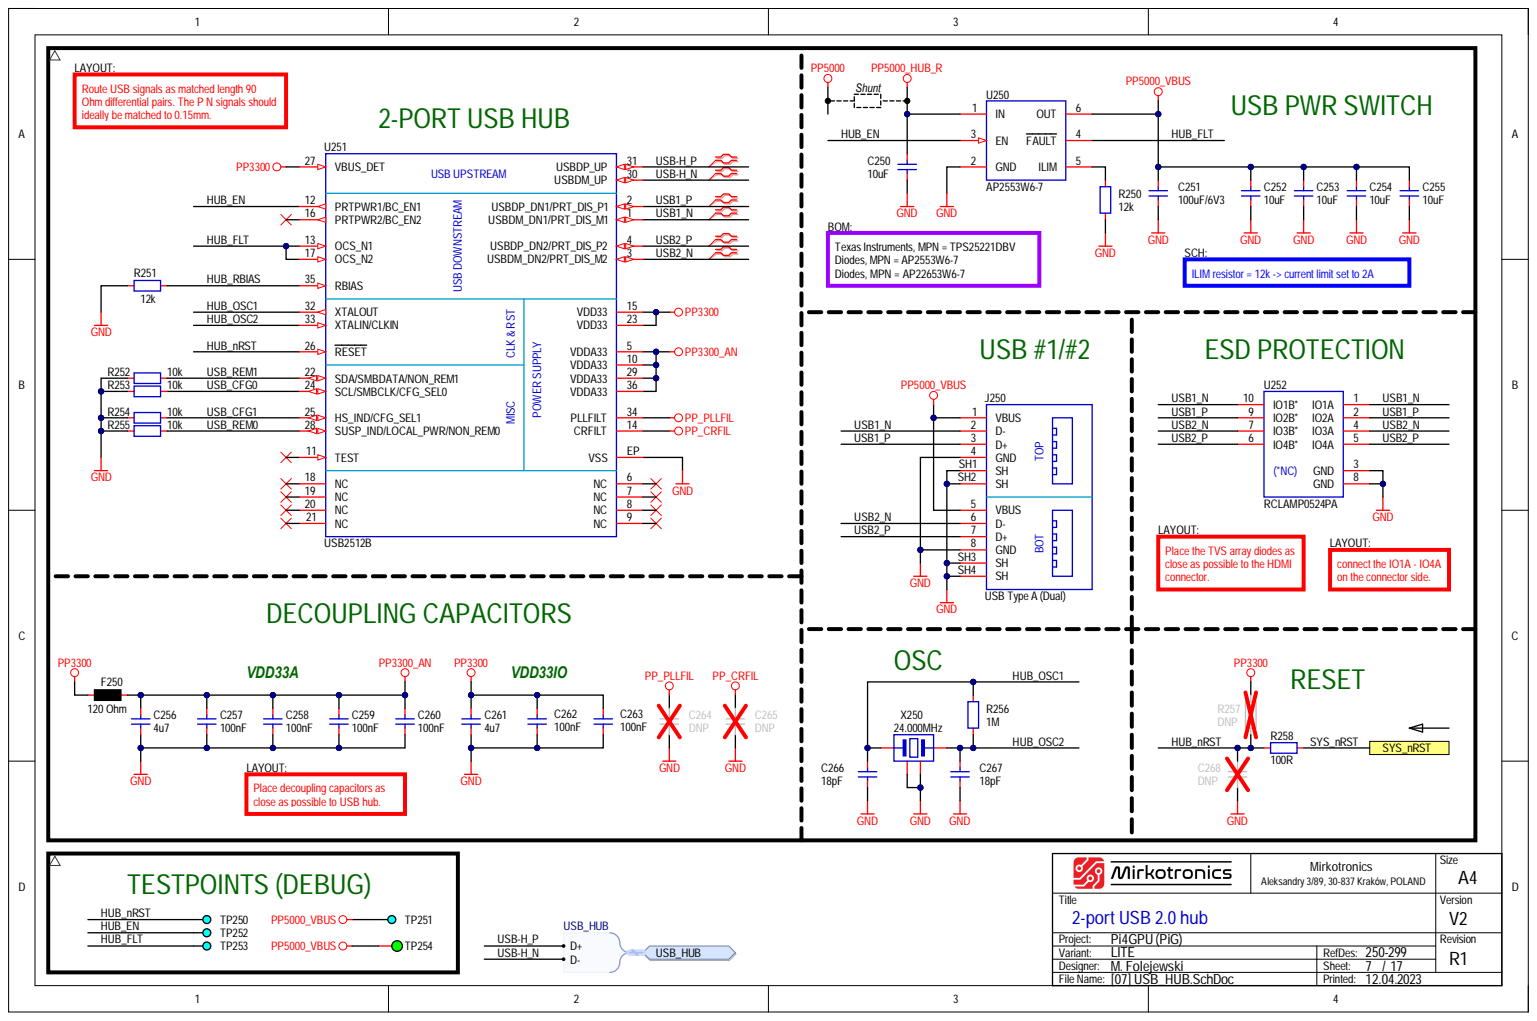
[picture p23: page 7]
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

SCH:
ILIM resistor = 12k -> current limit set to 2A

Place the TVS array diodes as
close as possible to the HDMI
connector.

connect the IO1A - IO4A
on the connector side.

Place decoupling capacitors as
close as possible to USB hub.

File Name: [07] USB_HUB.SchDoc | Printed:

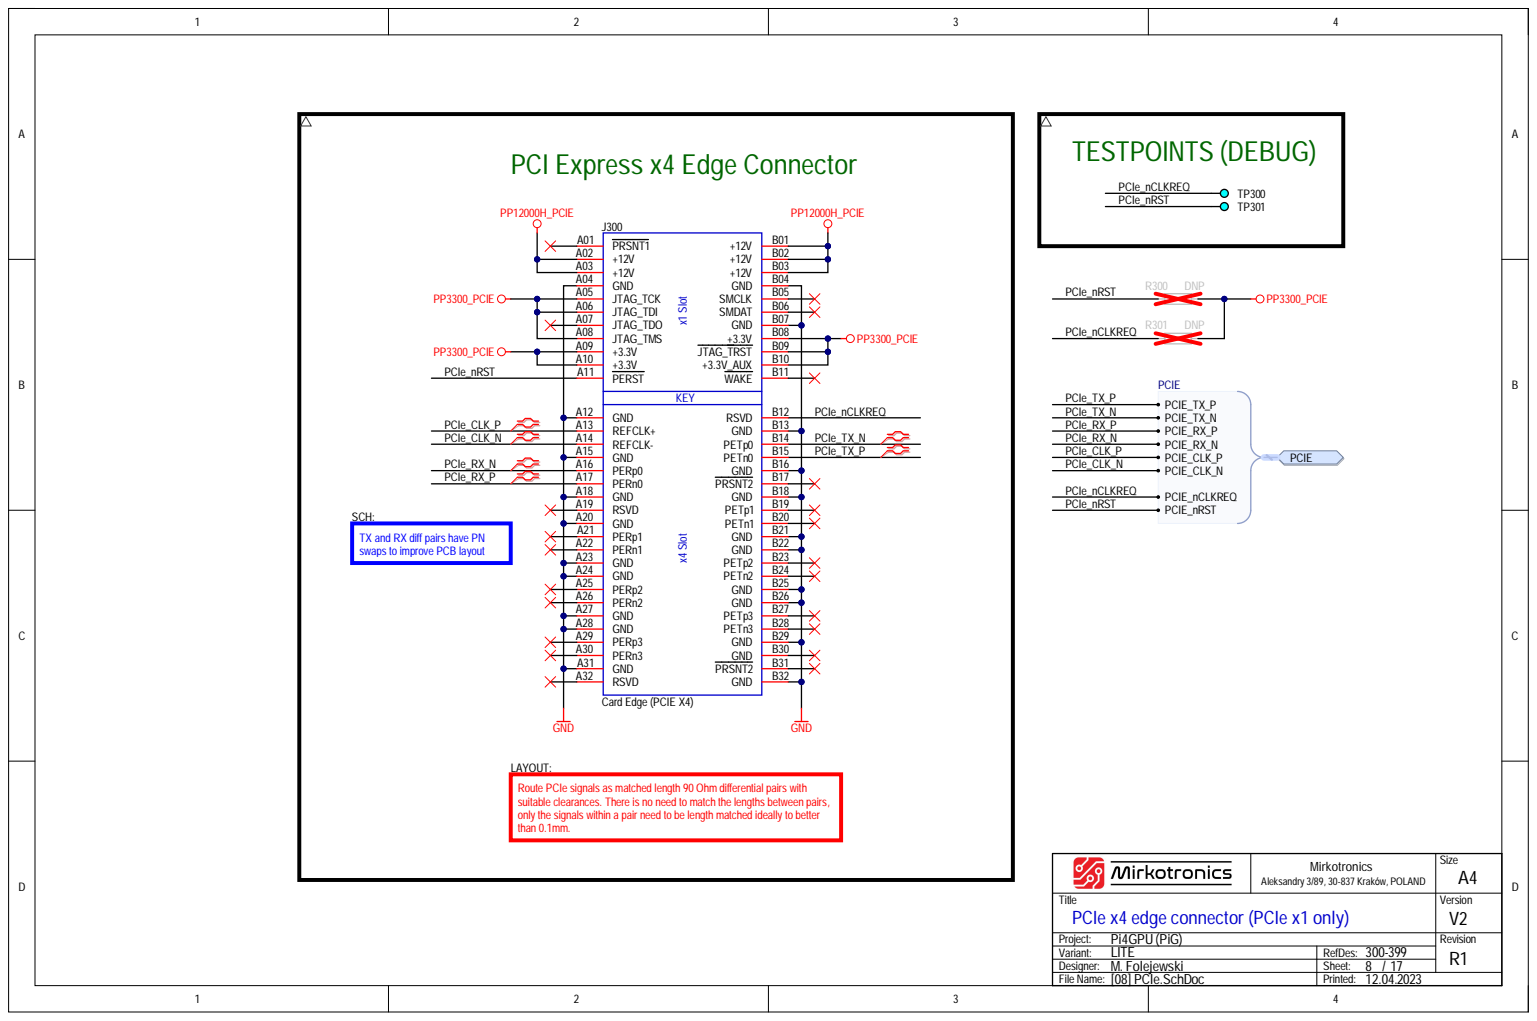
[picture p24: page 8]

PCI Express x4 Edge Connector

nd RX diff pairs have PN
ps to improve PCB layout

LAYOU
Route PCIe signals as matched le
suita
only the signals within a pair need to be le
tha

here is no need to match the le

ngth matched ideally to better

Mirkotro n i cs A leksandry 3/89, 30-837 Kraków, POLAND | Siz e A4

Titl e PCIe x4 edge connector (PCIe x1 only) | | Ve rsion V2
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

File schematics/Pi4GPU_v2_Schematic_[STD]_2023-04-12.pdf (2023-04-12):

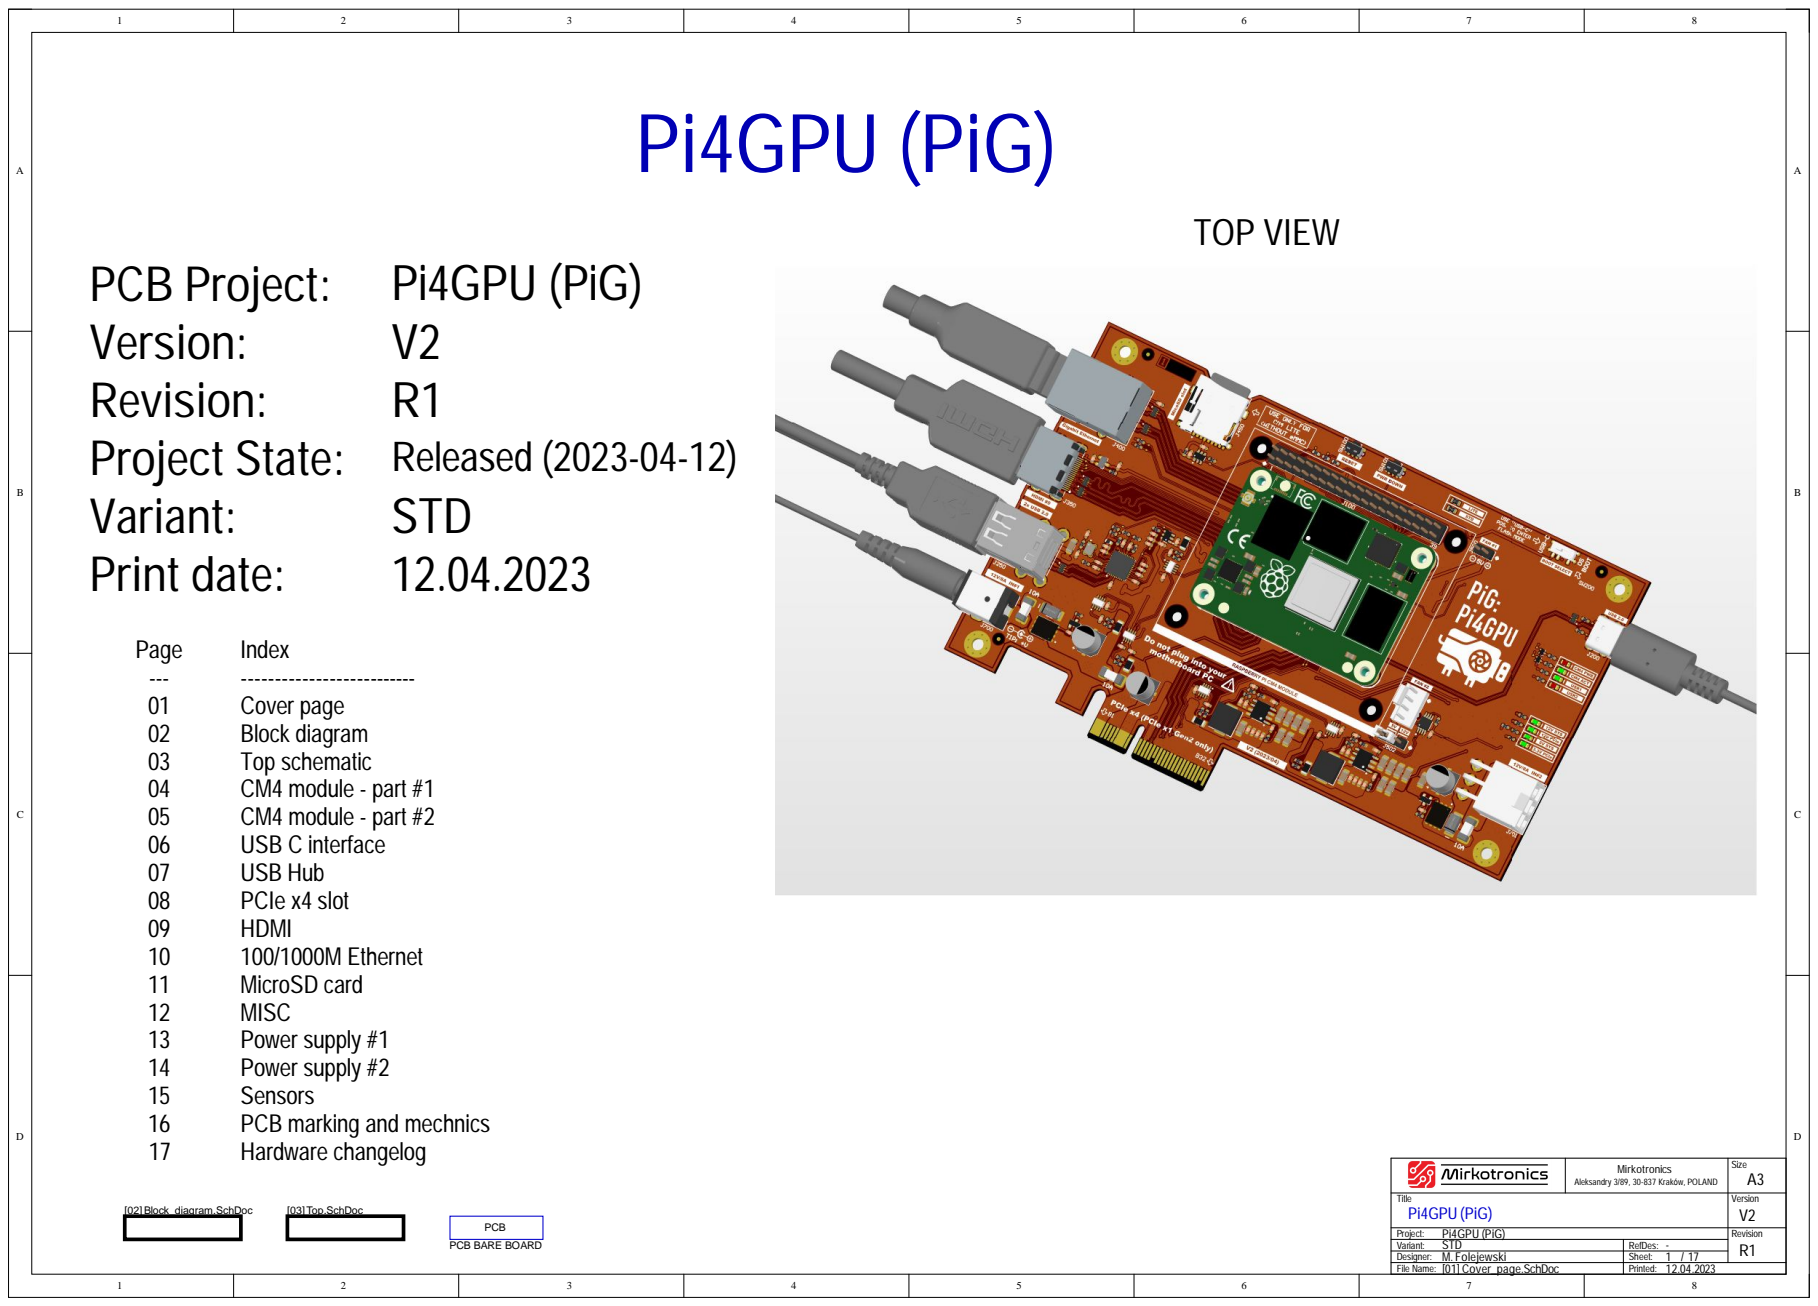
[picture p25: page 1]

Mirkotronics Aleksandry 3/89, 30-837 Kraków, POLAND | Size A3

Title Pi4GPU (PiG) | | Version V2

Revision R1
Variant: STD
Designer: M. Folejewski
File Name: [01] Cover_page.SchDoc | Printed:

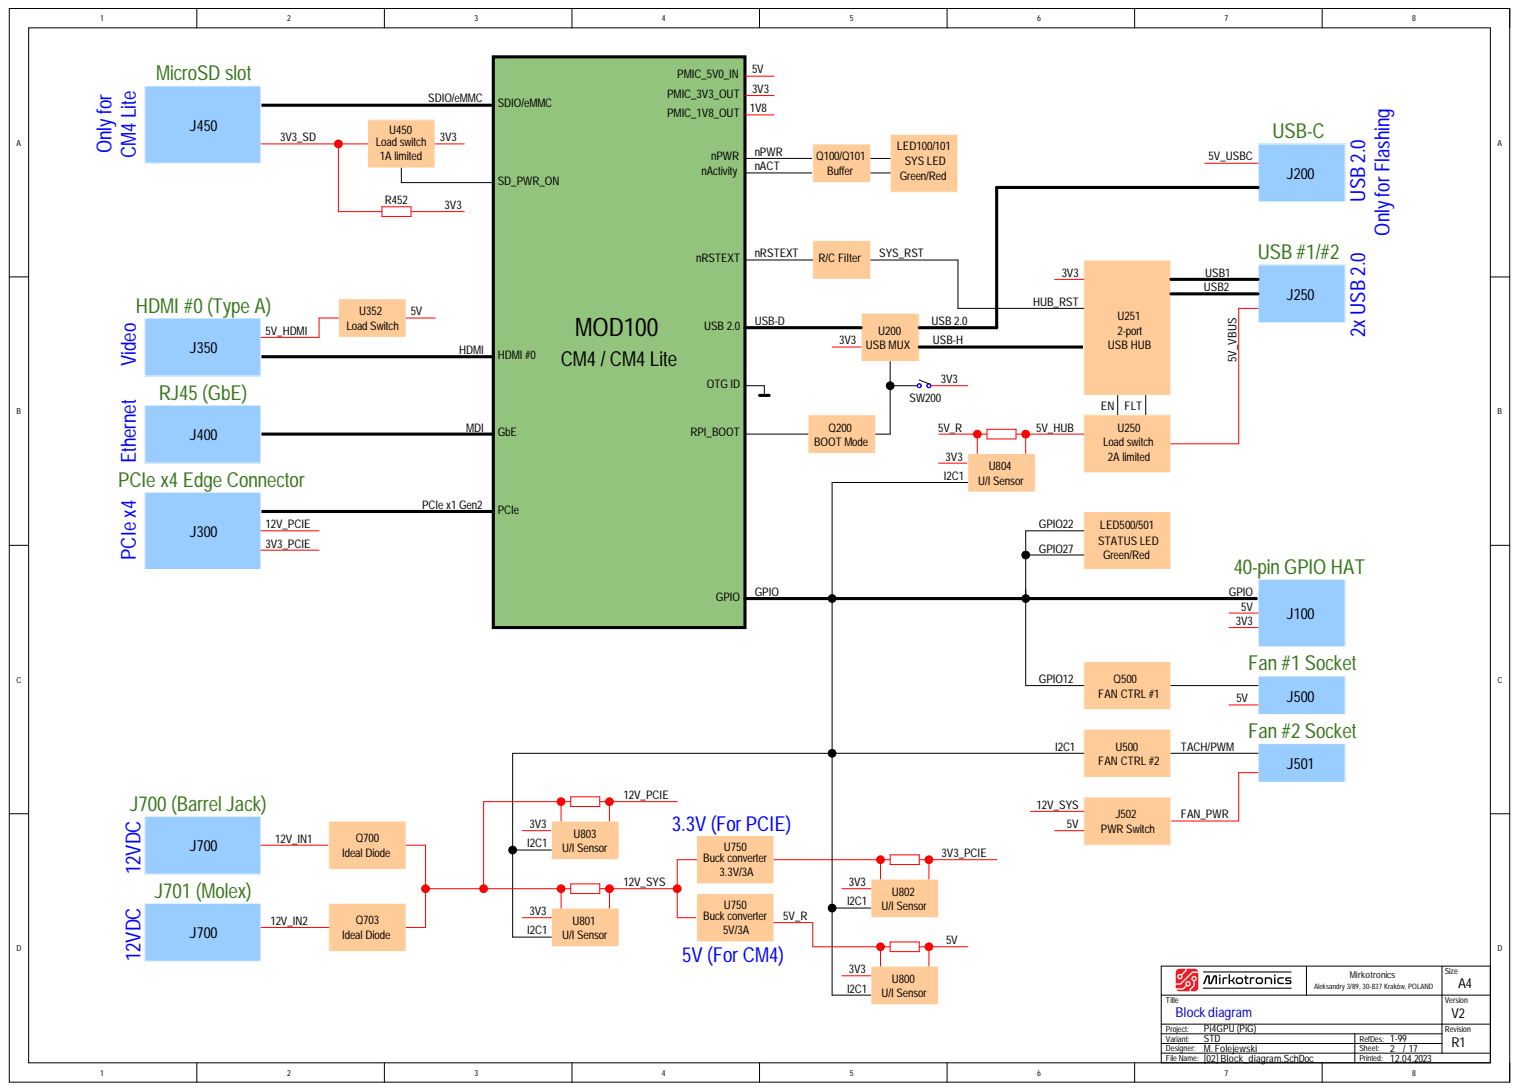
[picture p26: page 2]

SDIO/eMMC

Title Block diagram | Version V2

Revision R1
Variant: STD

File Name: [02] Block_diagram.SchDoc | Printed:


Mirkotronics Aleksandry 3/89, 30-837 Kraków, POLAND | Size A4

Title Top schematic | | Version V2

Project: Pi4GPU (PiG) | | Revision R1
Variant: STD | RefDes: 1-99

Sheet: 3 17 /

File Name: [03] TOP.SchDoc | Printed: 12.04.2023

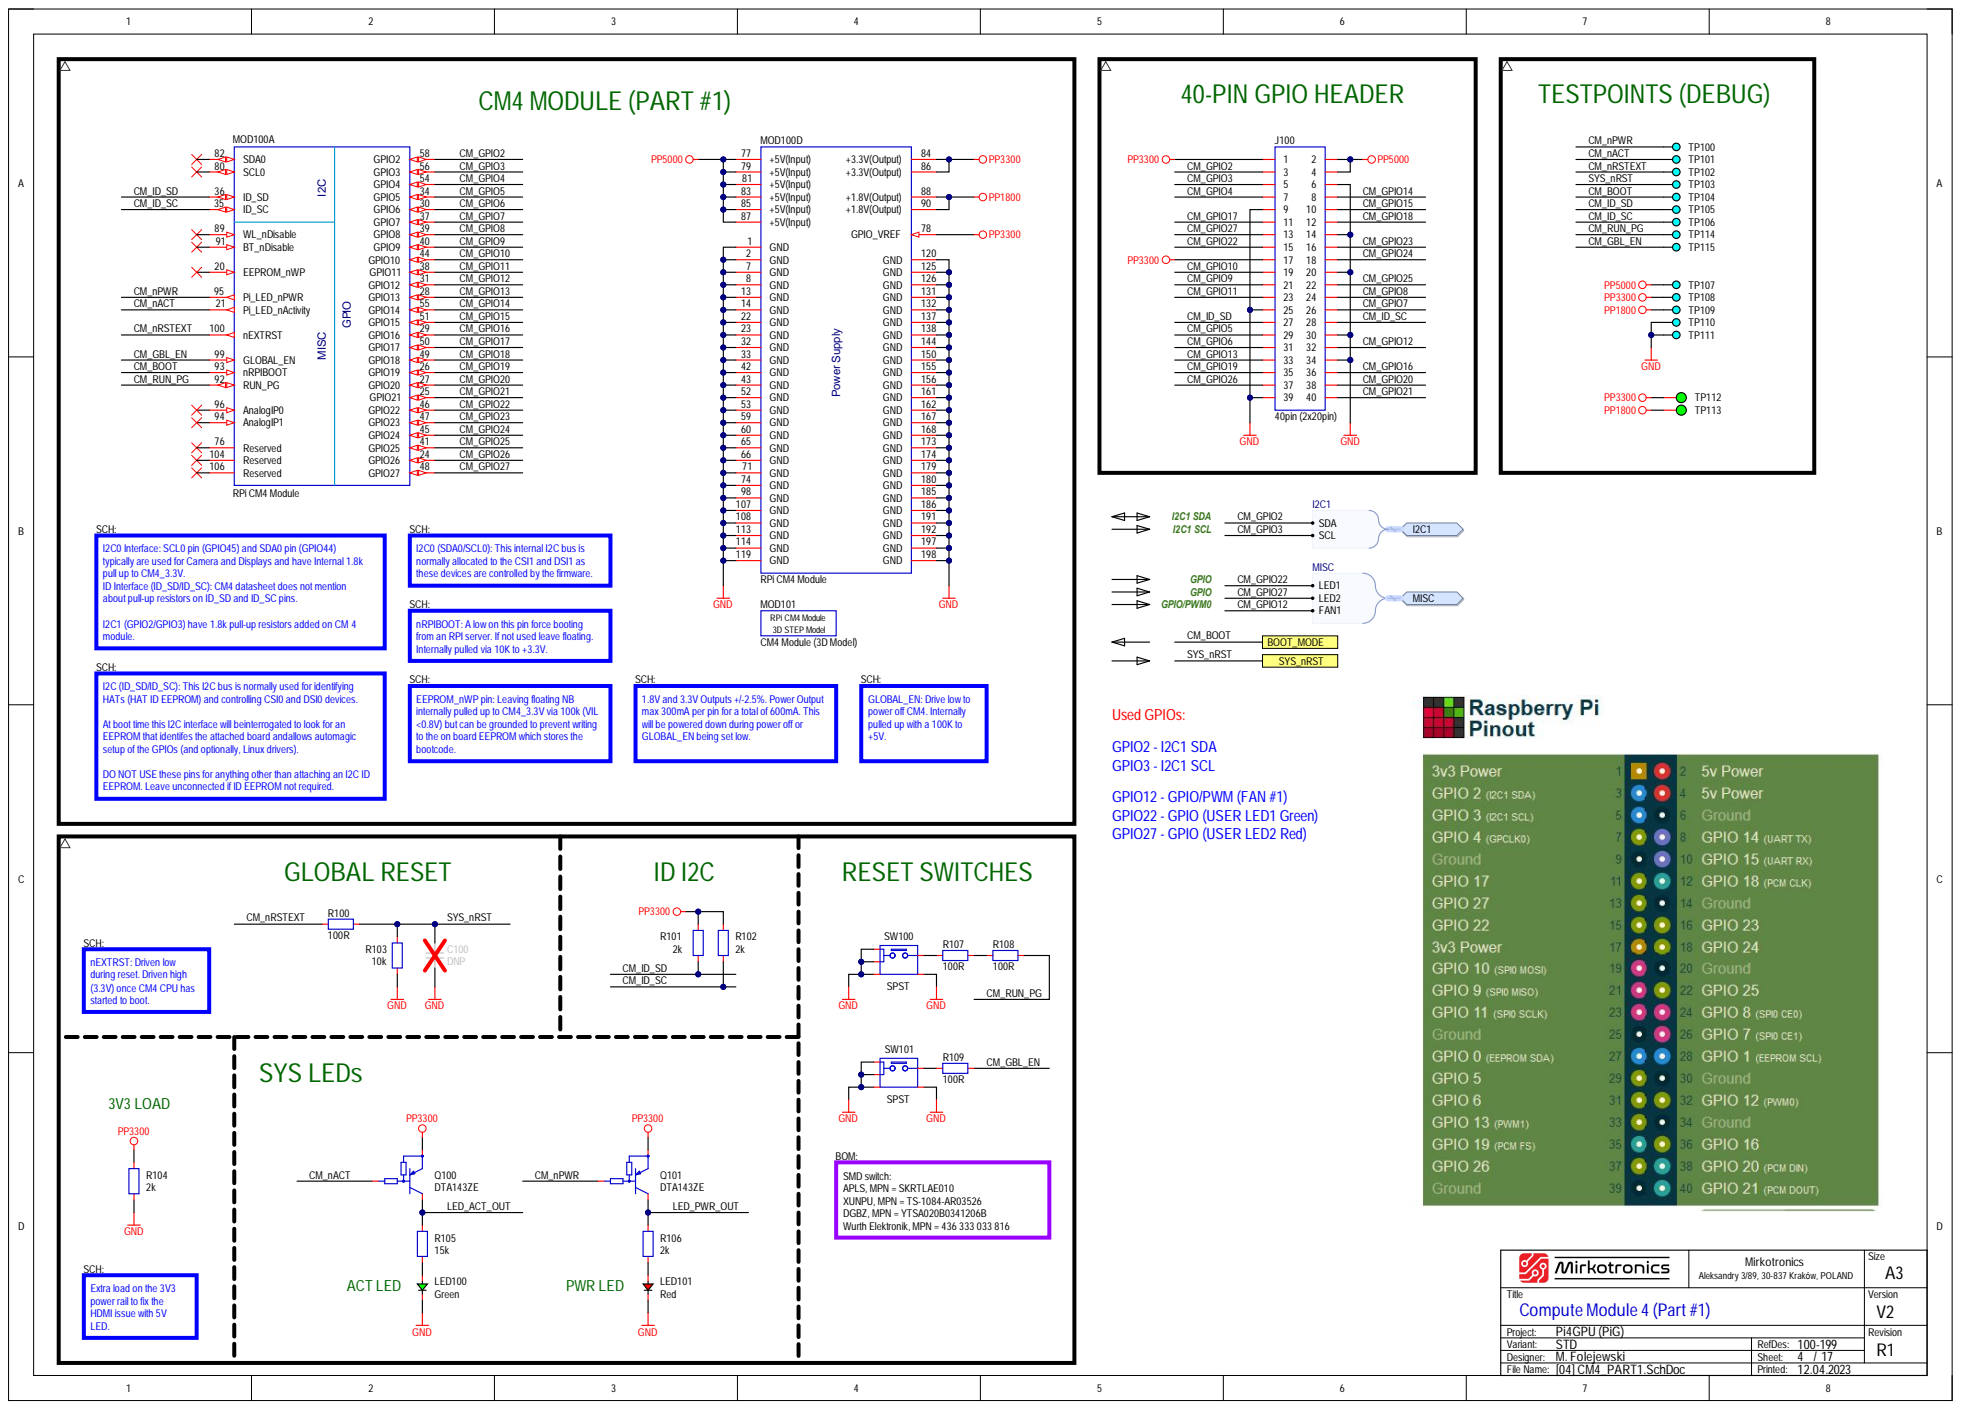
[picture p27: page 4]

SCH:
I2C0 Interface: SCL0 pin (GPIO45) and SDA0 pin (GPIO44)
typically are used for Camera and Displays and have Internal 1.8k
pull up to CM4_3.3V.
ID Interface (ID_SD/ID_SC): CM4 datasheet does not mention
about pull-up resistors on ID_SD and ID_SC pins.

I2C0 (SDA0/SCL0): This internal I2C bus is
normally allocated to the CSI1 and DSI1 as
these devices are controlled by the firmware.

nRPIBOOT: A low on this pin force booting
from an RPI server. If not used leave floating.
Internally pulled via 10K to +3.3V.

I2C1 (GPIO2/GPIO3) have 1.8k pull-up resistors added on CM4
module.

I2C (ID_SD/ID_SC): This I2C bus is normally used for identifying
HATs (HAT ID EEPROM) and controlling CSI0 and DSI0 devices.

EEPROM_nWP pin: Leaving floating NB
internally pulled up to CM4_3.3V via 100k (VIL
<0.8V) but can be grounded to prevent writing
to the on board EEPROM which stores the
bootcode.

1.8V and 3.3V Outputs +/-2.5%. Power Output
max 300mA per pin for a total of 600mA. This
will be powered down during power off or
GLOBAL_EN being set low.

GLOBAL_EN: Drive low to
power off CM4. Internally
pulled up with a 100K to

At boot time this I2C interface will beinterrogated to look for an
EEPROM that identifes the attached board andallows automagic
setup of the GPIOs (and optionally, Linux drivers).

DO NOT USE these pins for anything other than attaching an I2C ID
EEPROM. Leave unconnected if ID EEPROM not required.

nEXTRST: Driven low
during reset. Driven high
(3.3V) once CM4 CPU has
started to boot.

Mirkotronics Aleksandry 3/89, 30-837 Kraków, POLAND | Size A3

Extra load on the 3V3
power rail to fix the
HDMI issue with 5V
LED.

Title Compute Module 4 (Part #1) | | Version V2

Revision R1
Variant: STD

File Name: [04] CM4_PART1.SchDoc | Printed:

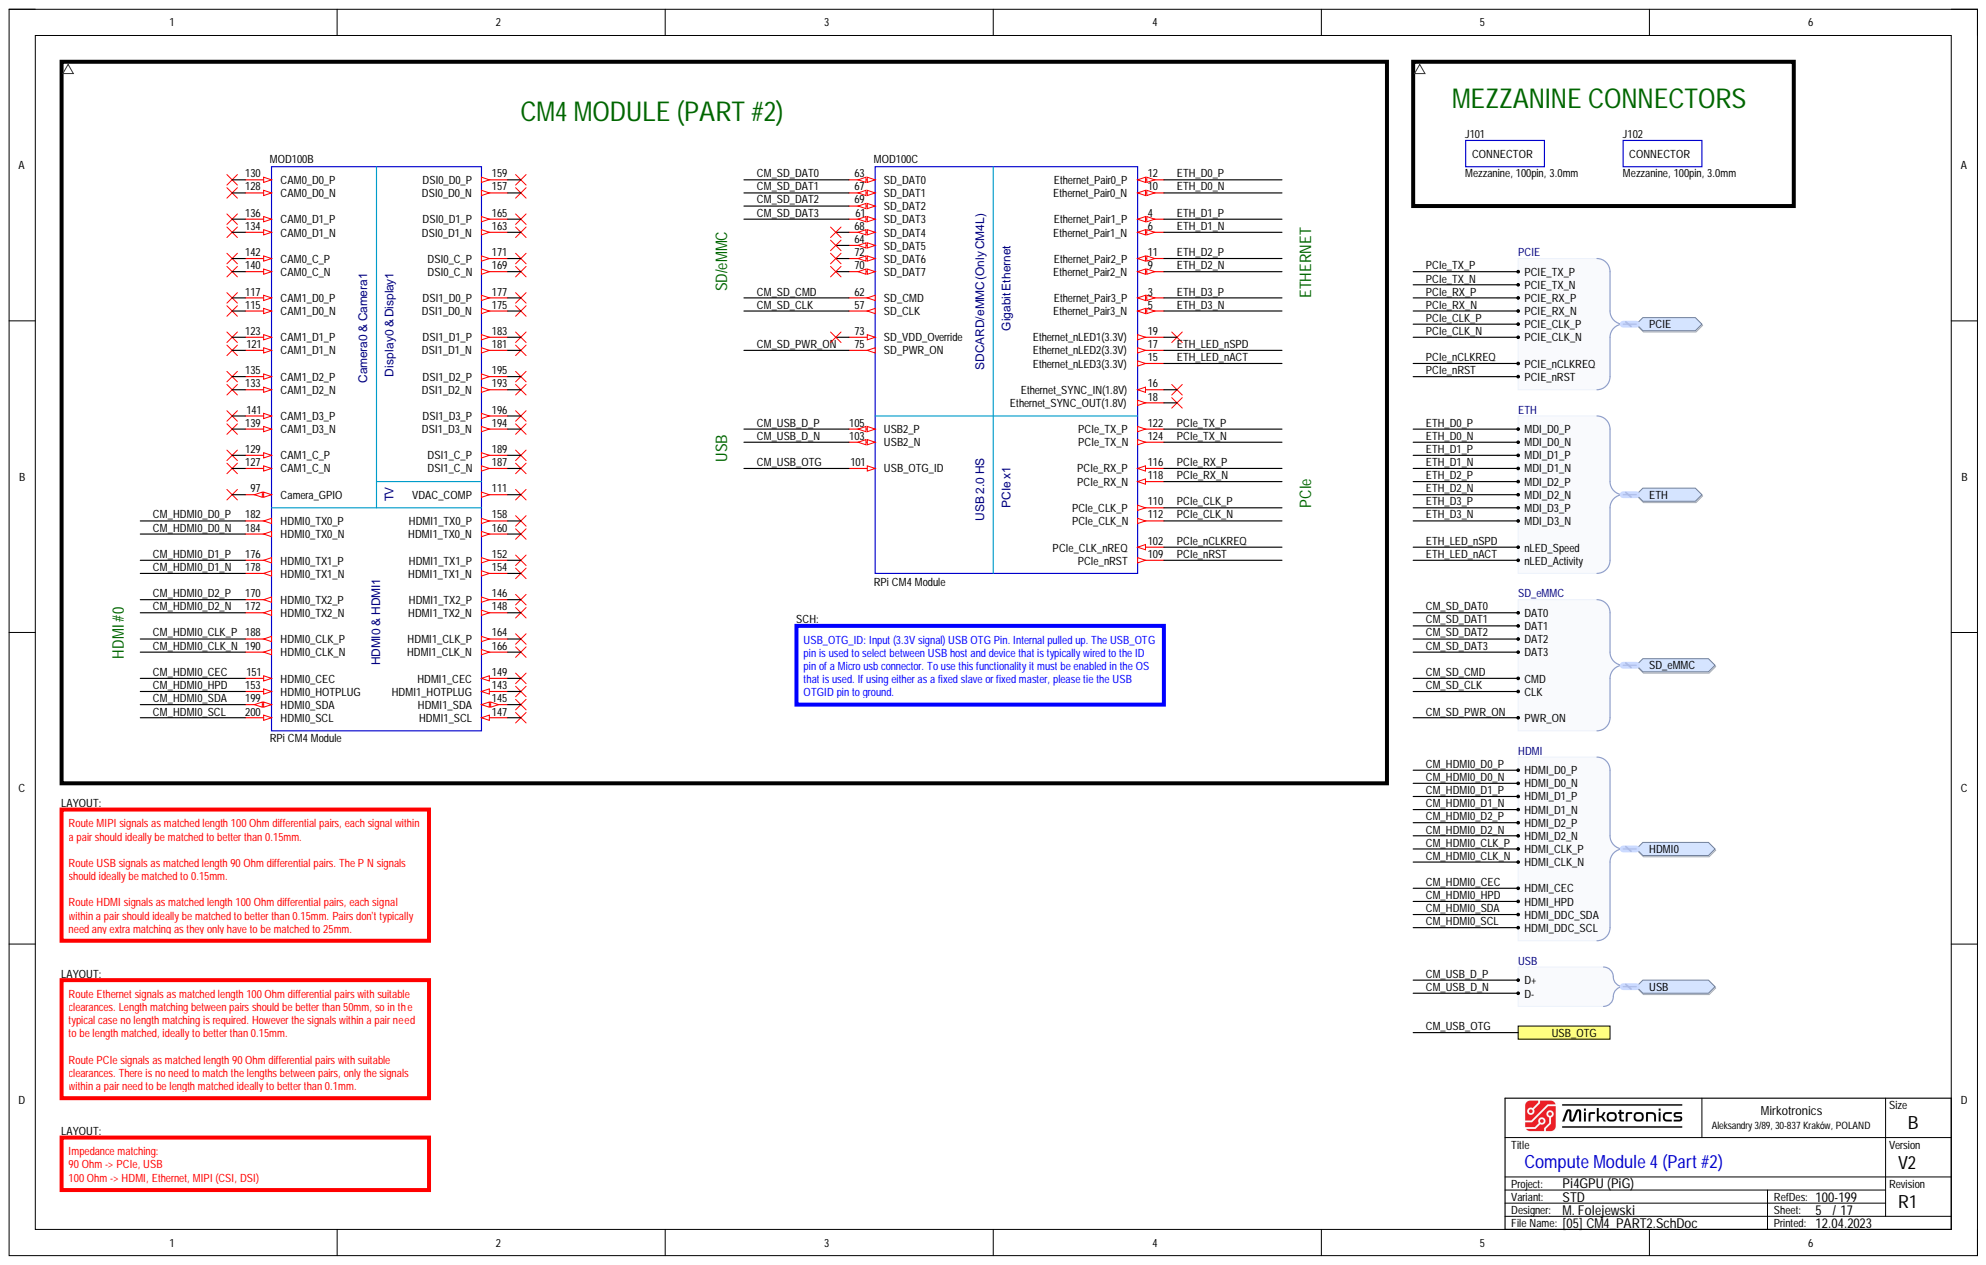
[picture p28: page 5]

SDCARD/eMMC(Only CM4L) USB 2.0 HS

select between USB host and devi
connector. To use

Revi sion R1
Variant: STD
M. Folejewski Designer: | Sheet:
Fi le Name: [05] CM4_PART2.SchDoc | Printed:


D1+ A6 | VBUS
D1- A7 | A9
D2+ B6 | B4

GND VBUS PDC SEC

USER:
USB_OTG line: if USB-C cable is connected
and SW200 jumper has shorted 2-3 pins then
the CM4 becomes a USB Device.

USB DEVICE MODE JUMPER:
1-2 = USB Device disabled (OS BOOT).
2-3 = CM4 connected as USB Device to USB-C cable.

Place the TVS array diodes as close
as possible to the USB-C connector.

connect the IO1A - IO4A
on the connector side.

BOM:
USB 3.1 Type C:
Use XKB Connectivity, MPN = U262-161N-4BVC11.
Description: vertical connector, 16 pins, USB 2.0 only,
SMD version.

LAYOUT:
Route USB signals as matched length 90 Ohm
differential pairs. The P N signals should ideally be
matched to 0.15mm.

Mirkotronics Aleksandry 3/89, 30-837 Kraków, POLAND | Size A4

Title USB-C interface and USB mux | | Version V2

Project: Pi4GPU (PiG) | | Revision R1
Variant: STD | RefDes: 200-249

File Name: [06] USB_C.SchDoc | Printed:

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

SCH:
ILIM resistor = 12k -> current limit set to 2A

Place the TVS array diodes as
close as possible to the HDMI
connector.

connect the IO1A - IO4A
on the connector side.

Place decoupling capacitors as
close as possible to USB hub.

File Name: [07] USB_HUB.SchDoc | Printed:


PCI Express x4 Edge Connector

nd RX diff pairs have PN
ps to improve PCB layout

LAYOU
Route PCIe signals as matched le
suita
only the signals within a pair need to be le
tha

here is no need to match the le

ngth matched ideally to better

Mirkotro n i cs A leksandry 3/89, 30-837 Kraków, POLAND | Siz e A4

Titl e PCIe x4 edge connector (PCIe x1 only) | | Ve rsion V2
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

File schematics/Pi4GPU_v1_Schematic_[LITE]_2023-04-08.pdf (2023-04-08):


Mirkotronics Aleksandry 3/89, 30-837 Kraków, POLAND | Size A3

Title Pi4GPU (PiG) | | Version V1

Revision R1
Variant: LITE
Designer: M. Folejewski
File Name: [01] Cover_page.SchDoc | Printed:


SDIO/eMMC

Title Block diagram | Version V1

Revision R1
Variant: LITE

File Name: [02] Block_diagram.SchDoc | Printed:


Mirkotronics Aleksandry 3/89, 30-837 Kraków, POLAND | Size A4

Title Top schematic | | Version V1

Project: Pi4GPU (PiG) | | Revision R1
Variant: LITE | RefDes: 1-99

Sheet: 3 15 /

File Name: [03] TOP.SchDoc | Printed: 08.04.2023


1 07 | 1 86
1 08 | 1 91
1 1 3 | 1 92

GPIO27 - GPIO (USER LED2 Red) I2C1 SDA I2C1 SCL

Mi r k o tro n i cs Aleksa nd ry 3/89, 30-837 K ra ków, POLAND | S i z e A 3

T i tl e C o m p u te Mod ule 4 (Part #1) | | Versi on V1

P i 4G P U (P i G ) Proj ect: | | R evi s i on R 1
Vari a n t: L I T E | R efDes : 1 00-1 99
Des i g ner: M. F o l ej ews ki | S hee t: 4 / 1 5
F i l e N ame : [04] C M4_PA R T 1 . S ch Doc | Pri n ted : 08. 04. 2023


SDCARD/eMMC(Only CM4L) USB 2.0 HS

select between USB host and devi
connector. To use

Revi sion R1
Variant: LITE
M. Folejewski Designer: | Sheet:
Fi le Name: [05] CM4_PART2.SchDoc | Printed:


USER:
USB_OTG line: if USB-C cable is connected
and SW200 jumper has shorted 2-3 pins then
the CM4 becomes a USB Device.

D1+ A6 | VBUS
D1- A7 | A9
D2+ B6 | B4

GND VBUS PDC SEC

USB DEVICE MODE JUMPER:
1-2 = USB Device disabled (OS BOOT).
2-3 = CM4 connected as USB Device to USB-C cable.

Place the TVS array diodes as close
as possible to the USB-C connector.

connect the IO1A - IO4A
on the connector side.

BOM:
USB 3.1 Type C:
Use XKB Connectivity, MPN = U262-161N-4BVC11.
Description: vertical connector, 16 pins, USB 2.0 only,
SMD version.

LAYOUT:
Route USB signals as matched length 90 Ohm
differential pairs. The P N signals should ideally be
matched to 0.15mm.

Mirkotronics Aleksandry 3/89, 30-837 Kraków, POLAND | Size A4

Title USB-C interface and USB mux | | Version V1

Project: Pi4GPU (PiG) | | Revision R1
Variant: LITE | RefDes: 200-249

File Name: [06] USB_C.SchDoc | Printed:


SCH:
ILIM resistor = 12k #NAME? current limit set to

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

D+ 3 D- 2 GND 4

Place the TVS array diodes as close
as possible to the HDMI connector.

Place decoupling capacitors as
close as possible to USB hub.

File Name: [07] USB_HUB.SchDoc | Printed:


PCI Express x4 Edge Connector

nd RX diff pairs have PN
ps to improve PCB layout

LAYOU
Route PCIe signals as matched le
suita
only the signals within a pair need to be le
tha

here is no need to match the le

ngth matched ideally to better

Mirkotro n i cs A leksandry 3/89, 30-837 Kraków, POLAND | Siz e A4

Titl e PCIe x4 edge connector (PCIe x1 only) | | Ve rsion V1

Project: Pi4G PU (PiG ) | | Revision
Va ria nt: LIT E R1 | RefDes: 300-399
Designer: M. Folejews ki | Sheet: 8 / 1 5
me: [08] PCIe.S ch Doc File Na | Printed 08.04. 2023 :


Place the TVS array diodes as close
as possible to the HDMI connector.

connect the IO1A - IO4A
on the connector side.

BOM:
HDMI #0 connector:
Wurth Elektronik, MPN = 685 119 134 923
BOOMELE, MPN = HDMI-001
Description: Type A (Standard), 19 pins, 0.50mm pitch, horizontal, SMD.

LAYOUT:
Route HDMI signals as matched length 100 Ohm differential pairs, each
signal within a pair should ideally be matched to better than 0.15mm. Pairs
don’t typically need any extra matching as they only have to be matched to

Mirkotronics Aleksandry 3/89, 30-837 Kraków, POLAND | Size A4

Title HDMI Interface | | Version V1

Project: Pi4GPU (PiG) | | Revision R1
Variant: LITE | RefDes: 400-449

File Name: [09] HDMI.SchDoc | Printed:


LAYOUT:
Route Ethernet signals as matched length 100 Ohm differential pairs
with suitable clearances. Length matching between pairs should be
better than 50mm, so in the typical case no length matching is required.
However the signals within a pair need to be length matched, ideally to
better than 0.15mm.

BOM:
RJ45 -> compatible connectors:
HanRun, MPN = HR911130A (HY911130A)
Link-PP, MPN = LPJG0806FBNL
Description: 100/1000M RJ45, Tab-down, G/Y LEDs

Place TVS array diodes as close
as possible to RJ45 connector.
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

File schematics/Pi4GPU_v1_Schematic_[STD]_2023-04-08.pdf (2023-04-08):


Mirkotronics Aleksandry 3/89, 30-837 Kraków, POLAND | Size A3

Title Pi4GPU (PiG) | | Version V1

Revision R1
Variant: STD_PRO
Designer: M. Folejewski
File Name: [01] Cover_page.SchDoc | Printed:


SDIO/eMMC

Title Block diagram | Version V1

Revision R1
Variant: STD_PRO

File Name: [02] Block_diagram.SchDoc | Printed:


Mirkotronics Aleksandry 3/89, 30-837 Kraków, POLAND | Size A4

Title Top schematic | | Version V1

Project: Pi4GPU (PiG) | | Revision R1
Variant: STD_PRO | RefDes: 1-99

Sheet: 3 15 /

File Name: [03] TOP.SchDoc | Printed: 08.04.2023


1 07 | 1 86
1 08 | 1 91
1 1 3 | 1 92

GPIO27 - GPIO (USER LED2 Red) I2C1 SDA I2C1 SCL

Mi r k o tro n i cs Aleksa nd ry 3/89, 30-837 K ra ków, POLAND | S i z e A 3

T i tl e C o m p u te Mod ule 4 (Part #1) | | Versi on V1

P i 4G P U (P i G ) Proj ect: | | R evi s i on R 1
Vari a n t: S T D_P R O | R efDes : 1 00-1 99
Des i g ner: M. F o l ej ews ki | S hee t: 4 / 1 5
F i l e N ame : [04] C M4_PA R T 1 . S ch Doc | Pri n ted : 08. 04. 2023


SDCARD/eMMC(Only CM4L) USB 2.0 HS

select between USB host and devi
connector. To use

Revi sion R1
Variant: STD_PRO
M. Folejewski Designer: | Sheet:
Fi le Name: [05] CM4_PART2.SchDoc | Printed:


USER:
USB_OTG line: if USB-C cable is connected
and SW200 jumper has shorted 2-3 pins then
the CM4 becomes a USB Device.

D1+ A6 | VBUS
D1- A7 | A9
D2+ B6 | B4

GND VBUS PDC SEC

USB DEVICE MODE JUMPER:
1-2 = USB Device disabled (OS BOOT).
2-3 = CM4 connected as USB Device to USB-C cable.

Place the TVS array diodes as close
as possible to the USB-C connector.

connect the IO1A - IO4A
on the connector side.

BOM:
USB 3.1 Type C:
Use XKB Connectivity, MPN = U262-161N-4BVC11.
Description: vertical connector, 16 pins, USB 2.0 only,
SMD version.

LAYOUT:
Route USB signals as matched length 90 Ohm
differential pairs. The P N signals should ideally be
matched to 0.15mm.

Mirkotronics Aleksandry 3/89, 30-837 Kraków, POLAND | Size A4

Title USB-C interface and USB mux | | Version V1

Project: Pi4GPU (PiG) | | Revision R1
Variant: STD_PRO | RefDes: 200-249

File Name: [06] USB_C.SchDoc | Printed:


SCH:
ILIM resistor = 12k #NAME? current limit set to

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

D+ 3 D- 2 GND 4

Place the TVS array diodes as close
as possible to the HDMI connector.

Place decoupling capacitors as
close as possible to USB hub.

File Name: [07] USB_HUB.SchDoc | Printed:


PCI Express x4 Edge Connector

nd RX diff pairs have PN
ps to improve PCB layout

LAYOU
Route PCIe signals as matched le
suita
only the signals within a pair need to be le
tha

here is no need to match the le

ngth matched ideally to better

Mirkotro n i cs A leksandry 3/89, 30-837 Kraków, POLAND | Siz e A4

Titl e PCIe x4 edge connector (PCIe x1 only) | | Ve rsion V1

Project: Pi4G PU (PiG ) | | Revision
Va ria nt: STD_P R O R1 | RefDes: 300-399
Designer: M. Folejews ki | Sheet: 8 / 1 5
me: [08] PCIe.S ch Doc File Na | Printed 08.04. 2023 :


Place the TVS array diodes as close
as possible to the HDMI connector.

connect the IO1A - IO4A
on the connector side.

BOM:
HDMI #0 connector:
Wurth Elektronik, MPN = 685 119 134 923
BOOMELE, MPN = HDMI-001
Description: Type A (Standard), 19 pins, 0.50mm pitch, horizontal, SMD.

LAYOUT:
Route HDMI signals as matched length 100 Ohm differential pairs, each
signal within a pair should ideally be matched to better than 0.15mm. Pairs
don’t typically need any extra matching as they only have to be matched to

Mirkotronics Aleksandry 3/89, 30-837 Kraków, POLAND | Size A4

Title HDMI Interface | | Version V1

Project: Pi4GPU (PiG) | | Revision R1
Variant: STD_PRO | RefDes: 400-449

File Name: [09] HDMI.SchDoc | Printed:


LAYOUT:
Route Ethernet signals as matched length 100 Ohm differential pairs
with suitable clearances. Length matching between pairs should be
better than 50mm, so in the typical case no length matching is required.
However the signals within a pair need to be length matched, ideally to
better than 0.15mm.

BOM:
RJ45 -> compatible connectors:
HanRun, MPN = HR911130A (HY911130A)
Link-PP, MPN = LPJG0806FBNL
Description: 100/1000M RJ45, Tab-down, G/Y LEDs

Place TVS array diodes as close
as possible to RJ45 connector.
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

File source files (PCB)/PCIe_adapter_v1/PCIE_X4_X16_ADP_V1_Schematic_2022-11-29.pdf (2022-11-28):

# PCIe x4

## KEYx16 Slot x1 Slot


LAYOUT:
Route PCIe signals as matched length 90 Ohm differential
pairs with suitable clearances. There is no need to match the
lengths between pairs, only the signals within a pair need to
be length matched ideally to better than 0.1mm.

Mirko Electronics Smoka Wawelskiego 1 30-535 Kraków, Poland | Size A4

Title PCIe x4/x16 Adapter | | Version VER1

Project: PCIe x4/x16 Adapter | | Revision REV1
Variant: [No Variations] | RefDes: 1-99
Designer: Smok Wawelski | Sheet: 1 1 /
File Name: | Printed: PCIE_X4_X16_ADP_V1.SchDoc 29.11.2022






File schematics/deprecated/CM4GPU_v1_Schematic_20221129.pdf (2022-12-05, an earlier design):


Mirko Electronics Smoka Wawelskiego 1 30-535 Kraków, Poland | Size A3

Title Pi4GPU (PiG) | | Version V1

Project: PiG (Pi4GPU) | | Revision R1
Variant: [No Variations] | RefDes: -
Designer: M. Folejewski
File Name: [01] Cover_page.SchDoc | Printed:


SDIO/eMMC

USB OTG OTG ID

Mirko Electronics Smoka Wawelskiego 1 30-535 Kraków, Poland | Size A4

Title Block diagram | | Version V1

Project: PiG (Pi4GPU) | | Revision R1
Variant: [No Variations] | RefDes: 1-99


Mirko Electronics Smoka Wawelskiego 1 30-535 Kraków, Poland | Size A4

Title Top schematic | | Version V1

Project: PiG(Pi4GPU) | | Revision R1
Variant: [No Variations] | RefDes: 1-99

Sheet: 3 15 /

File Name: [03] TOP.SchDoc | Printed: 29.11.2022


85 | 90
87 | 7 8

1 3 | 1 31
1 4 | 1 32
22 | 1 37

23 | 1 38
32 | 1 44

1 07 | 1 86
1 08 | 1 91
1 1 3 | 1 92

GPIO27 - GPIO (USER LED2 Red) I2C1 SDA I2C1 SCL

Mi r k o E l ec tro n i cs Smoka Wawelskiego 1 30-535 Kra kó w, Pol a nd | S i z e A 3

T i tl e C o m p u te Mod ule 4 (Part #1) | | Versi on V1

Proj ect: P i G (P i 4G P U ) | | R evi s i on R 1
Vari a n t: [ N o V a ri a ti o n s ] | R efDes : 1 00-1 99
Des i g ner: M. F o l ej ews ki | S hee t: 4 / 1 5
F i l e N ame : [04] C M4_PA R T 1 . S ch Doc | Pri n ted : 29. 1 1 . 2022


SDCARD/eMMC(Only CM4L) USB 2.0 HS

(3.3V signal
Input
to select between USB host and device
Micro usb connector. To use
is used.
OTG

rs, each signal withi

Route USB signals as
should

Route HDMI signals as
within a pai
need any extra

Route Ethernet signals as
clearances. Length
typical case no

fferential pai
than 50mm, so
the signals within a pai

Route PCIe signals as
clearances. There

Project: Pi G (Pi4GPU) | Revision R1
Variant: [No Variations] | RefDes: 100-199
Designer: M. Folejewski | Sheet:
Fi le Name: [05] CM4_PART2.SchDoc | Printed:


USER:
USB_OTG line: if USB-C cable is connected
and SW200 jumper has shorted 2-3 pins then
the CM4 becomes a USB Device.

GND VBUS PDC SEC

USB DEVICE MODE JUMPER:
1-2 = USB Device disabled (OS BOOT).
2-3 = CM4 connected as USB Device to USB-C cable.

Place the TVS array diodes as close
as possible to the USB-C connector.

connect the IO1A - IO4A
on the connector side.

BOM:
USB 3.1 Type C:
Use XKB Connectivity, MPN = U262-161N-4BVC11.
Description: vertical connector, 16 pins, USB 2.0 only,
SMD version.

LAYOUT:
Route USB signals as matched length 90 Ohm
differential pairs. The P N signals should ideally be
matched to 0.15mm.

Mirko Electronics Smoka Wawelskiego 1 30-535 Kraków, Poland | Size A4

Title USB-C interface and USB switch | | Version V1

Project: PiG(Pi4GPU) | | Revision R1
Variant: [No Variations] | RefDes: 200-249

File Name: [06] USB_C.SchDoc | Printed:


SCH:
ILIM resistor = 12k => current limit set to 2A
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

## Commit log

2023-04-06 Issue #2: Add an initial 3D model for a base.
    [gpu-stand.scad, gpu-stand.stl]
2023-04-07 Issue #2: Make the base fit on my tiny Ender 3 V2 bed.
    [gpu-stand.scad, gpu-stand.stl]
